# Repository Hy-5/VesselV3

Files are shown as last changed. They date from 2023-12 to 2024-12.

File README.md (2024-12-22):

# Vessel (rev 1.0)

Schematics

PCB 3D View

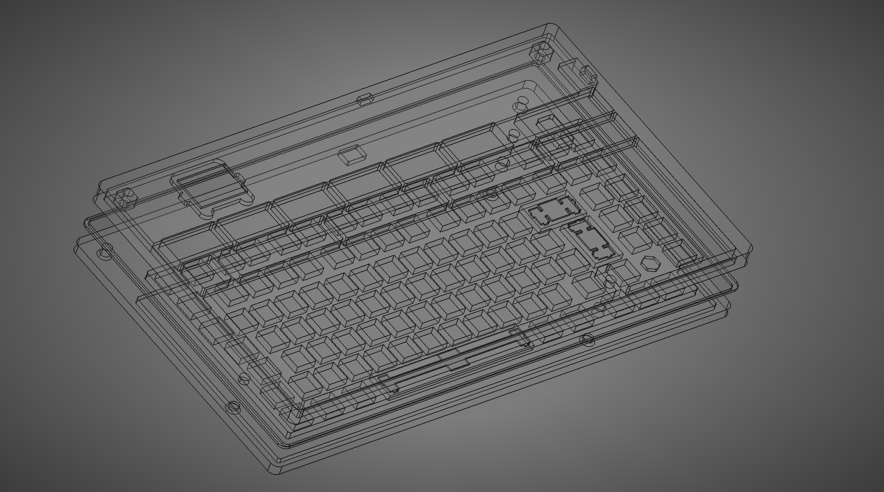
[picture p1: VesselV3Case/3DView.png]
Case 3D Model


Case Turntable

PCB before soldering

Soldered PCB

RgbOFF

Side View

RgbON

*ISO-FR 75-ish keyboard with I2C OLED, RGB (WS2812B-2020) and rotary encoder*

* Keyboard Maintainer: [Hy-5 (Ismael Coulibaly)](https://github.com/Hy-5)
* Hardware Supported: *STM32F446RET6TR*

[WIP]

Make example for this keyboard (after setting up your build environment):

    qmk compile -kb vessel -km base 2>&1 | ts '%Y-%m-%d %H:%M:%S

Flashing example for this keyboard:

    A - Initial flashing
        1 - Bridge "boot0 to 3v3_1" solder jumper to pull boot0 high
        2 - Desolder logic level shifter to keep boot1 pin low
        3 - Plug in the keyboard, it will boot in dfu bootloader mode
        4 - Use whatever program you prefer, QMK Toolbox, STM32 Programmer, STLink V2 etc.
    B - After initial flashing
        1 - Keep M12 button (row0, col11) pressed while plugging in the keyboard to launch in bootloader mode
        2 - Use QMK Toolbox for flashing

See the [build environment setup](https://docs.qmk.fm/#/getting_started_build_tools) and the [make instructions](https://docs.qmk.fm/#/getting_started_make_guide) for more information. Brand new to QMK? Start with our [Complete Newbs Guide](https://docs.qmk.fm/#/newbs).

## Bootloader

Enter the bootloader in 1 way:

* **Bootmagic reset**: Hold down the M12 key at ((row0, col11) in the matrix) and plug in the keyboard

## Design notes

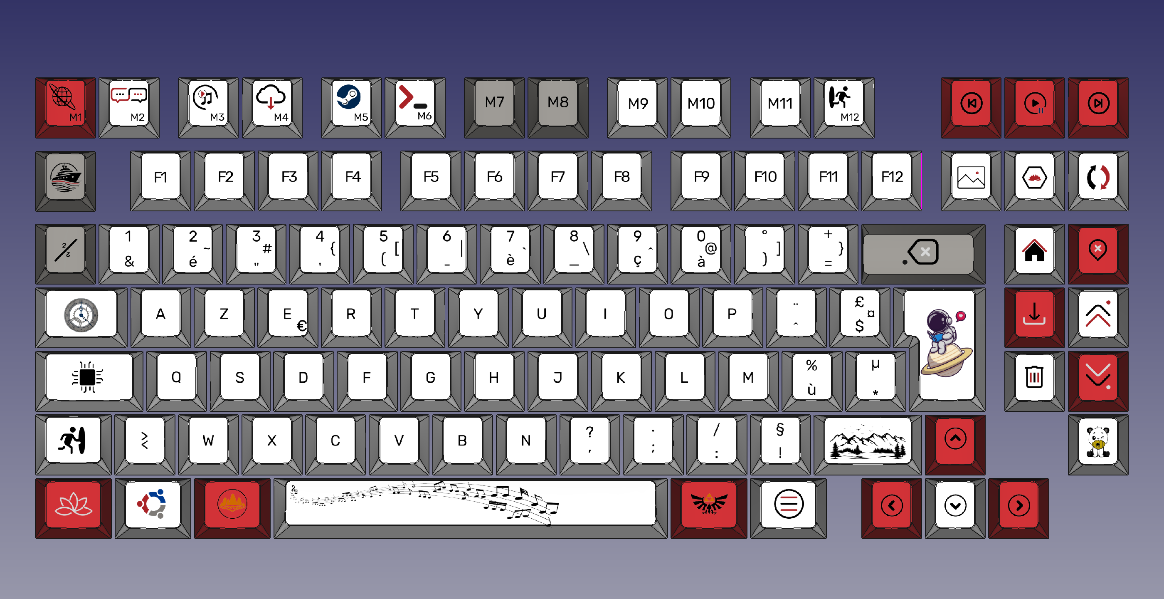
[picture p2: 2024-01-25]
VesselV3Case/Keycaps_Render.png

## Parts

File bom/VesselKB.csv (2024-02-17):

null | Sourced | Placed | References | Value | Footprint | DigikeyPartNumber | Manufacturer_Name | Manufacturer_Part_Number | Mouser Part Number | Quantity
1 |  |  | C3, C6, C7, C8, C16, C17, C19, C20, C21, C22, C23, C24 | 0.1u | C0805 | 399-C0805C104J8RAC7800TR-ND | KEMET | C0805C104J8RACTU | 80-C0805C104J8R | 12
2 |  |  | C9, C10, C11, C12, C13, C14, C15, C18, C29 | 4.7u | C0805 | 399-15708-2-ND | KEMET | C0805C475J8RACAUTO | 80-C0805C475J8RAUTO | 9
3 |  |  | C25, C26, C27 | 10n | CAPC2012X135N | 732-7579-2-ND | Wurth Elektronik | 885012007009 | 710-885012007009 | 3
4 |  |  | C1, C2 | 20pF | C0603 | 399-C0603C200G8HAC7867TR-ND | KEMET | C0603C200G8HACTU | 80-C0603C200G8HACTU | 2
5 |  |  | C4, C5 | 1u | CAPC2012X140N | 478-KGM21AR71A105JUTR-ND | AVX | 0805ZC105JAT2A | 581-0805ZC105JAT2A | 2
6 |  |  | C33 | c=10u | CAPC2012X135N | 1276-2402-2-ND | SAMSUNG | CL21A106KPFNNNF | 187-CL21A106KPFNNNF | 1
7 |  |  | R4, R12, R13, R14, R16, R18, R19, R21, R22 | 10k | RESC2012X50N | 541-CRCW080510K0JNECTR-ND | Vishay | CRCW080510K0JNEC | 71-CRCW080510K0JNEC | 9
8 |  |  | R1, R2 | r=5100 | RESC2012X60N | 2019-RK73H2ATTD5101FTR-ND | KOA Speer | RK73H2ATTD5101F | 660-RK73H2ATTD5101F | 2
9 |  |  | R10 | 320 | RESC1005X40N | 2019-RN73H1ETTP3200D25TR-ND | KOA Speer | RN73H1ETTP3200D25 | 660-RN73H1ETP3200D25 | 1
10 |  |  | R11 | r=22 | RESC2012X60N | CR0805-FX-22R0ELFTR-ND | Bourns | CR0805-FX-22R0ELF | 652-CR0805FX-22R0ELF | 1
11 |  |  | D1, D2, D3, D4, D5, D6, D7, D8, D9, D10, D11, D12, D13, D14, D15, D16, D17, D18, D19, D20, D21, D22, D23, D24, D25, D26, D27, D28, D29, D30, D31, D32, D33, D34, D35, D36, D37, D38, D39, D40, D41, D42, D43, D44, D45, D46, D47, D48, D49, D50, D51, D52, D53, D54, D55, D56, D57, D58, D59, D60, D61, D62, D63, D64, D65, D66, D67, D68, D69, D70, D71, D72, D73, D74, D75, D76, D77, D78, D79, D80, D81, D82, D83, D84, D85, D86, D87, D88, D89, D90, D91, D92, D93, D94, D95, D96, D97, D98, D99, D100, D101, D102 | D_Small | SODFL3816X120N | 4878-1N4148WTR-ND | Diotec Semiconductor | 1N4148W | 637-1N4148W | 102
12 |  |  | D103 | USBLC6-2SC6Y | SOT95P280X145-6N | 497-11882-2-ND | STMicroelectronics | USBLC6-2SC6Y | 511-USBLC6-2SC6Y | 1
13 |  |  | Y1 | 25MHz | ATS25ASM1E | CTX1144TR-ND | CTS | ATS25ASM-1E | 774-ATS25ASM-1E | 1
14 |  |  | (AND_Gate)IC6 | 74AUP1G09GW-Q100H | SOT65P212X110-5N | 1727-74AUP1G09GW-Q100HTR-ND | Nexperia | 74AUP1G09GW-Q100H | 771-74AUP1G09GWQ100H | 1
15 |  |  | (BidirectionalLogicLevelShifter)IC4 | TXB0104PWR | SOP65P640X120-14N | 296-21929-2-ND | Texas Instruments | TXB0104PWR | 595-TXB0104PWR | 1
16 |  |  | (LDORegulator)IC1 | AP2112K-3.3TRG1 | SOT95P282X130-5N | AP2112K-3.3TRG1DITR-ND | Diodes Incorporated | AP2112K-3.3TRG1 | 621-AP2112K-3.3TRG1 | 1
17 |  |  | (LF50ABDT-TR)-IC3 | 5VOutput_VoltageRegulator | TO228P972X240-3N | 497-8344-2-ND | STMicroelectronics | LF50ABDT-TR | 511-LF50ABDT-TR | 1
18 |  |  | MCU1 | STM32F446RET6TR | QFP50P1200X1200X160-64N | 497-STM32F446RET6TR-ND | STMicroelectronics | STM32F446RET6TR | 511-STM32F446RET6TR | 1
19 |  |  | Polyfuse1 | 500mA | 1206L05015YR | F3733TR-ND | LITTELFUSE | 1206L050/15YR | 576-1206L050/15YR | 1
20 |  |  | Q1 | BC856A,215 | SOT95P230X110-3N | 1727-4242-2-ND | Nexperia | BC856A,215 | 771-BC856A-T/R | 1
21 |  |  | Rotary_Encoder(20mm)_S4 | PEC12R-3220F-S0024 | PEC12R3220FS0024 | PEC12R-3220F-S0024-ND | Bourns | PEC12R-3220F-S0024 | 652-PEC12R3220FS0024 | 1
22 |  |  | S6 | On/On SPDT | SW_L102021ML04Q | CKC5102-ND | C&K | L102021ML04Q | 611-L102021ML04Q | 1
23 |  |  | Schottky/ReversPolProtec1 | PMEG2010ER,115 | PMEG2010ER115 | 1727-5192-2-ND | Nexperia | PMEG2010ER,115 | 771-PMEG2010ER115 | 1
24 |  |  | TVSDiode/ESDSuppr1 | SMF6.0CA | SODFL3618X108N | 18-SMF6.0CATR-ND | LITTELFUSE | SMF6.0CA | 576-SMF6.0CA | 1
25 |  |  | USB-C1 | USB4800-03-A | USB480003A | 2073-USB4800-03-ATR-ND | GCT (GLOBAL CONNECTOR TECHNOLOGY) | USB4800-03-A | 640-USB4800-03-A | 1
26 |  |  | J1 | JTAG/SWD 10pins Headers | HUSSP10W40P127_2X5_635X340X420P | 952-4189-2-ND | Harwin | M50-3600542R | 855-M50-3600542R | 1

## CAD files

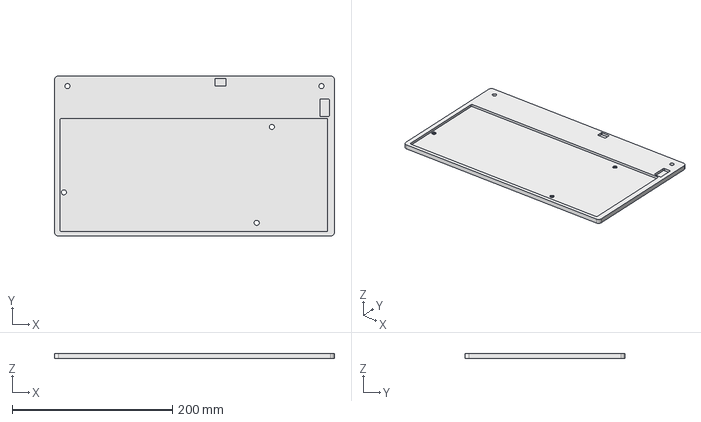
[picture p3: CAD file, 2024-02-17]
VesselV3Case/Final Models/1 - BottomLayer.step
350.0 x 200.0 x 6.50 mm

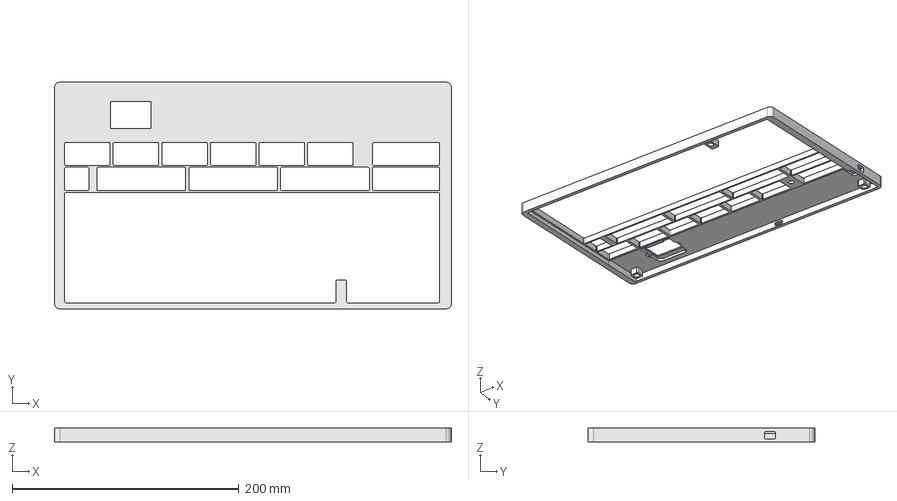
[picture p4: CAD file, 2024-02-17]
VesselV3Case/Final Models/2 - TopLayer.step
350.0 x 200.0 x 12.0 mm

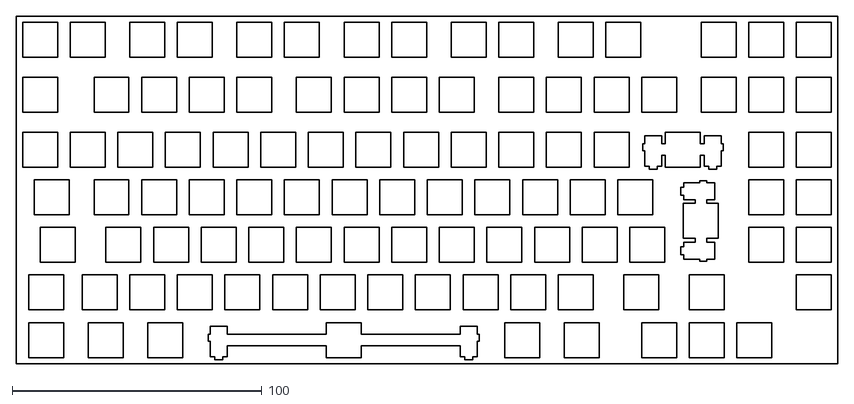
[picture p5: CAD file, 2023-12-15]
VesselV3Case/SwitchLayer/UpdatedSwitchLayer.dxf
328.6 x 139.1

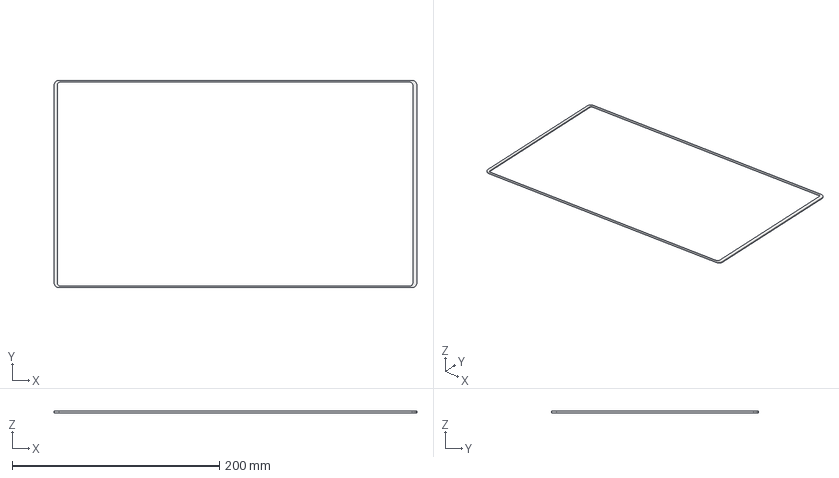
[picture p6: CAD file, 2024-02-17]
VesselV3Case/Final Models/4 - SideLayer.step
350.0 x 200.0 x 1.60 mm

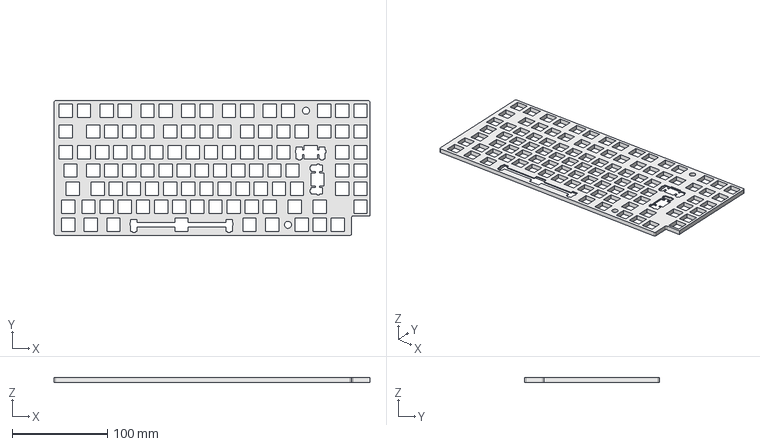
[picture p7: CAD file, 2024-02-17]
VesselV3Case/Final Models/3 - SwitchLayer.step
332.0 x 141.5 x 5.00 mm

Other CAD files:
VesselV3Case/SwitchLayer/SwitchLayerFile.FCStd
Silkscreen DXF/OLD_VesselV3-F_Silkscreen.dxf
Silkscreen DXF/VesselV3-F_Silkscreen.dxf

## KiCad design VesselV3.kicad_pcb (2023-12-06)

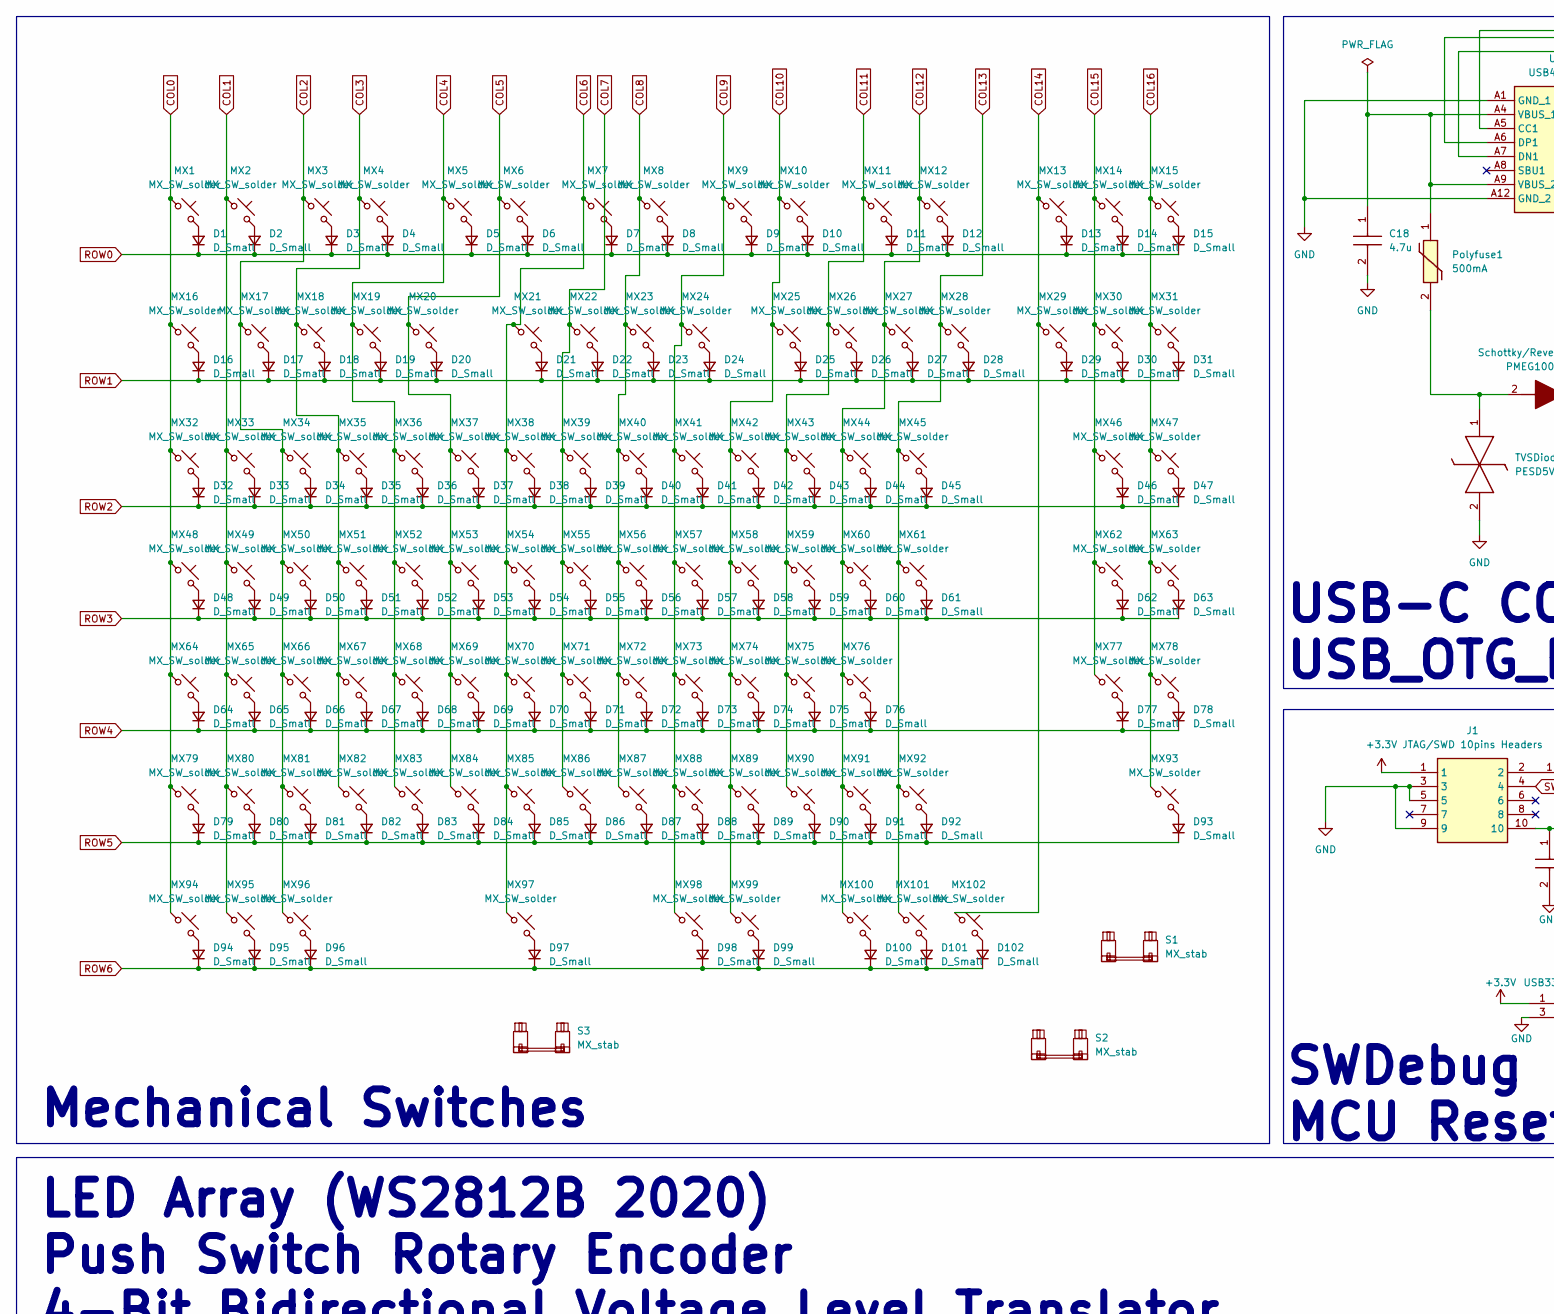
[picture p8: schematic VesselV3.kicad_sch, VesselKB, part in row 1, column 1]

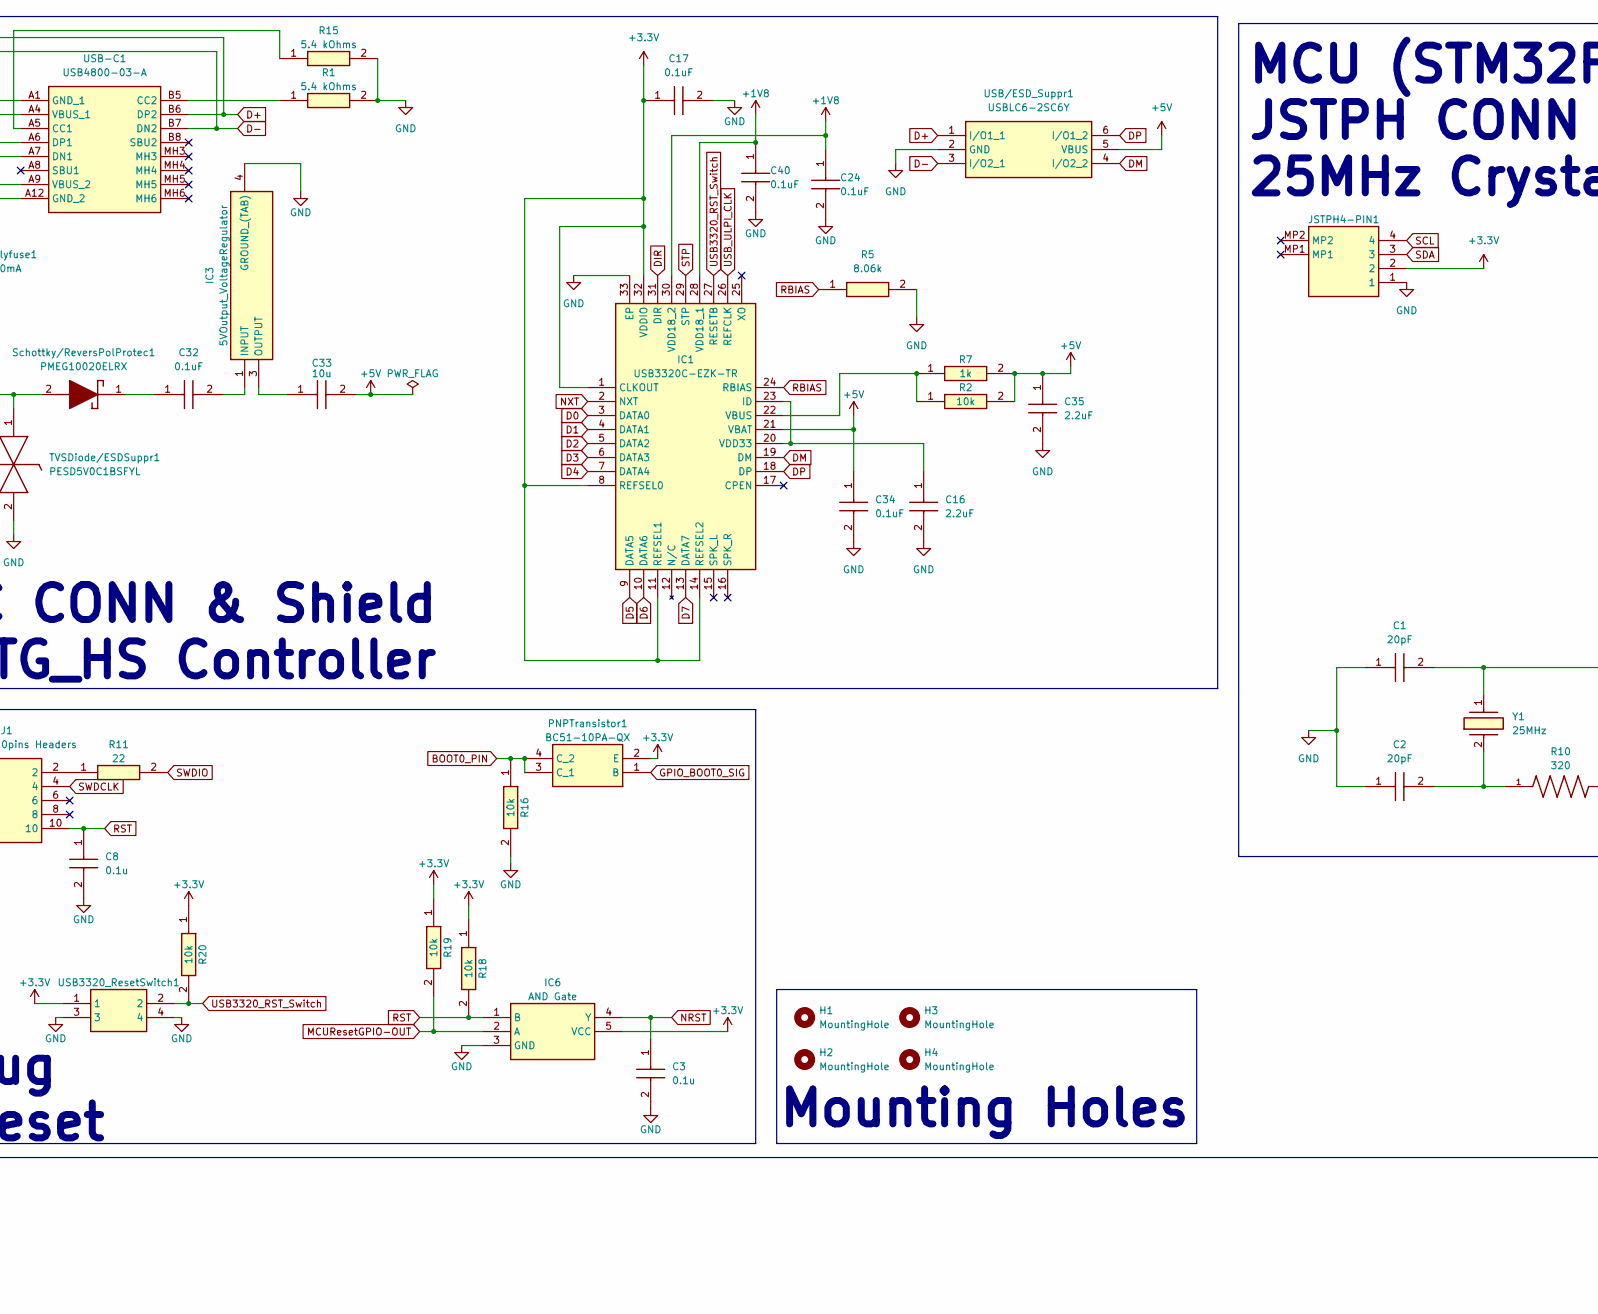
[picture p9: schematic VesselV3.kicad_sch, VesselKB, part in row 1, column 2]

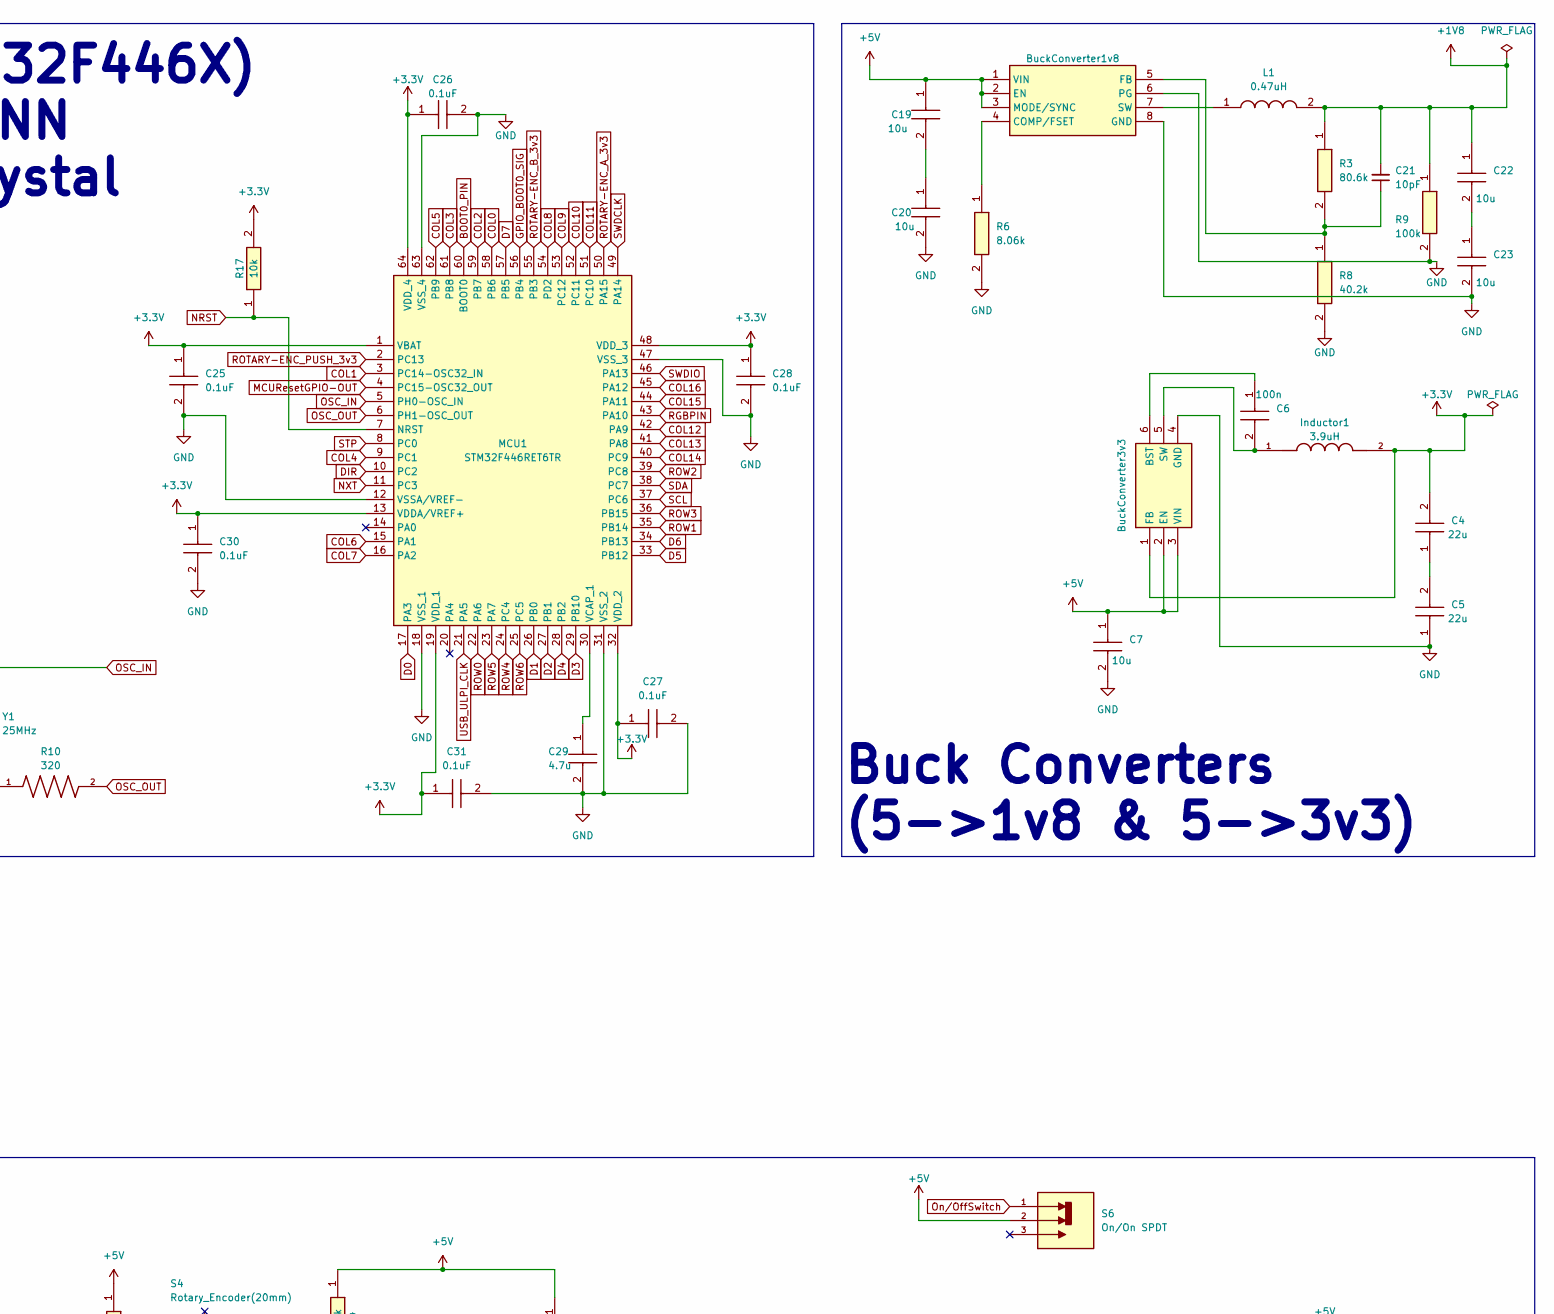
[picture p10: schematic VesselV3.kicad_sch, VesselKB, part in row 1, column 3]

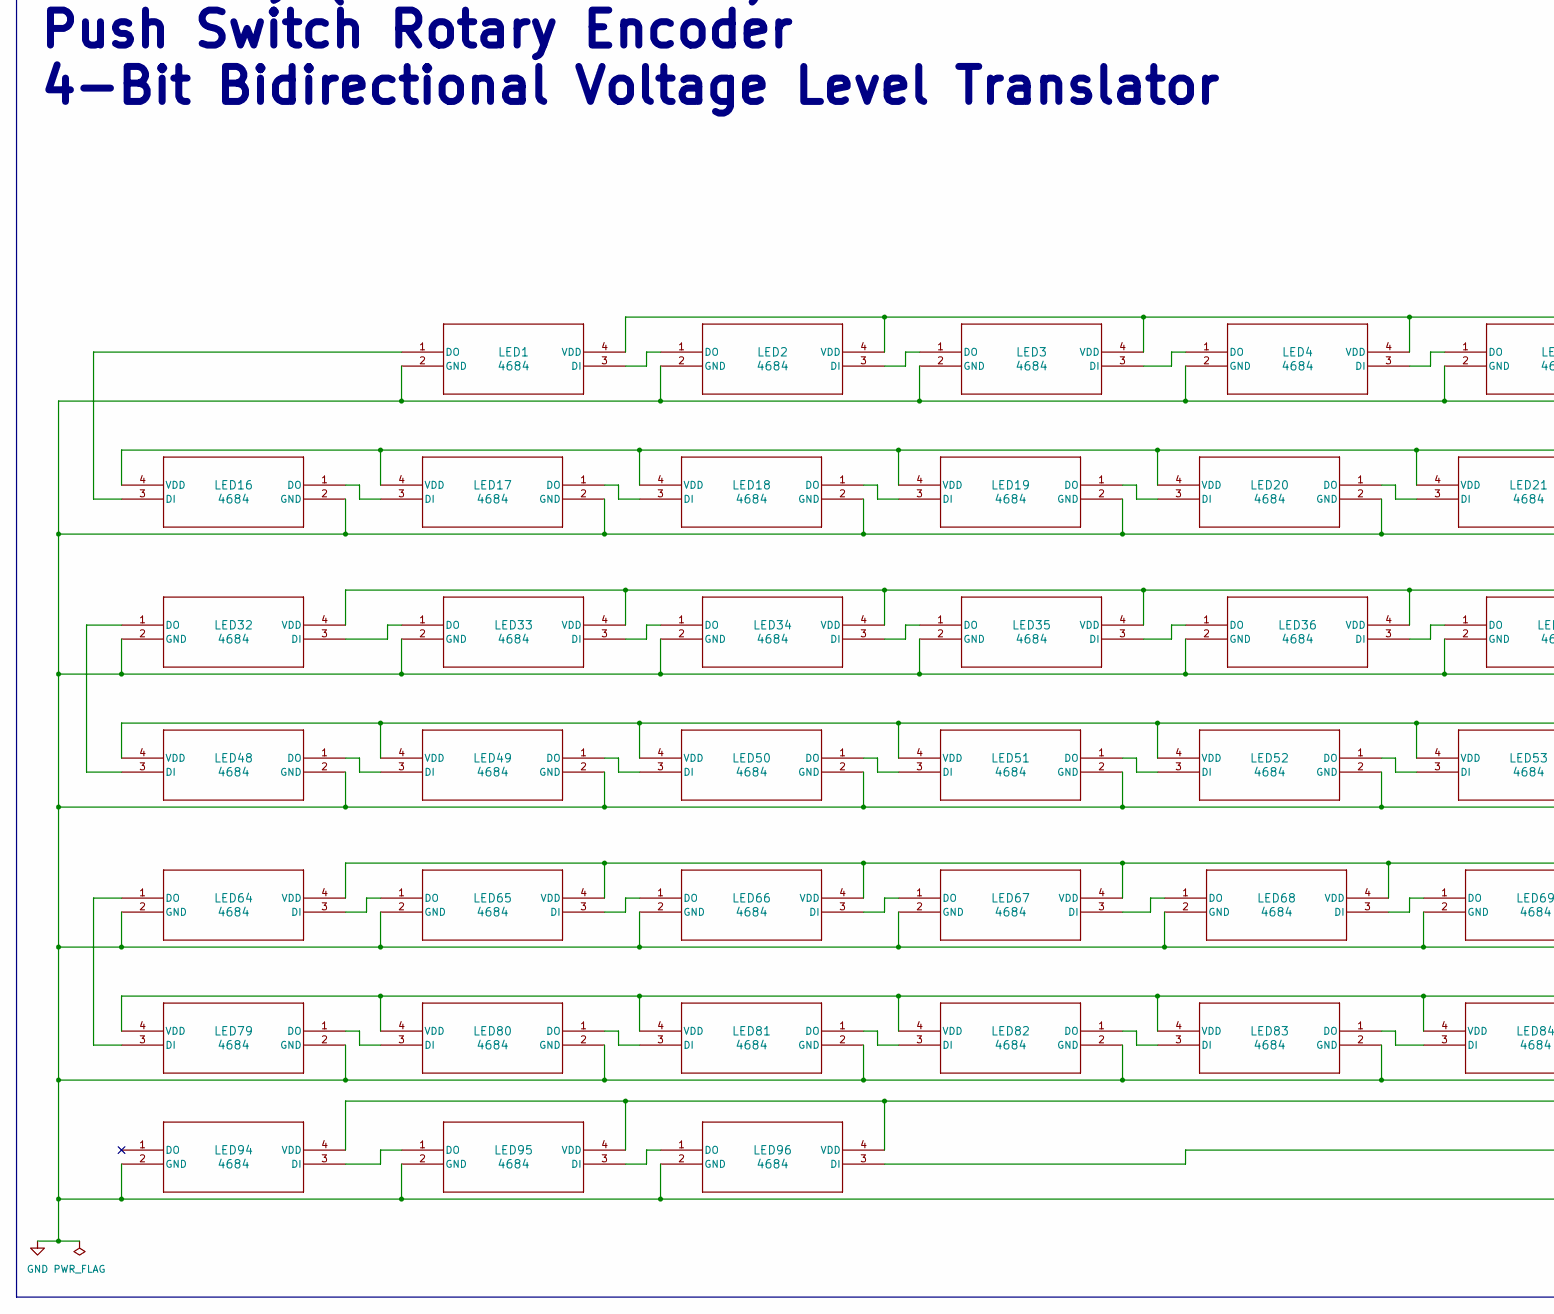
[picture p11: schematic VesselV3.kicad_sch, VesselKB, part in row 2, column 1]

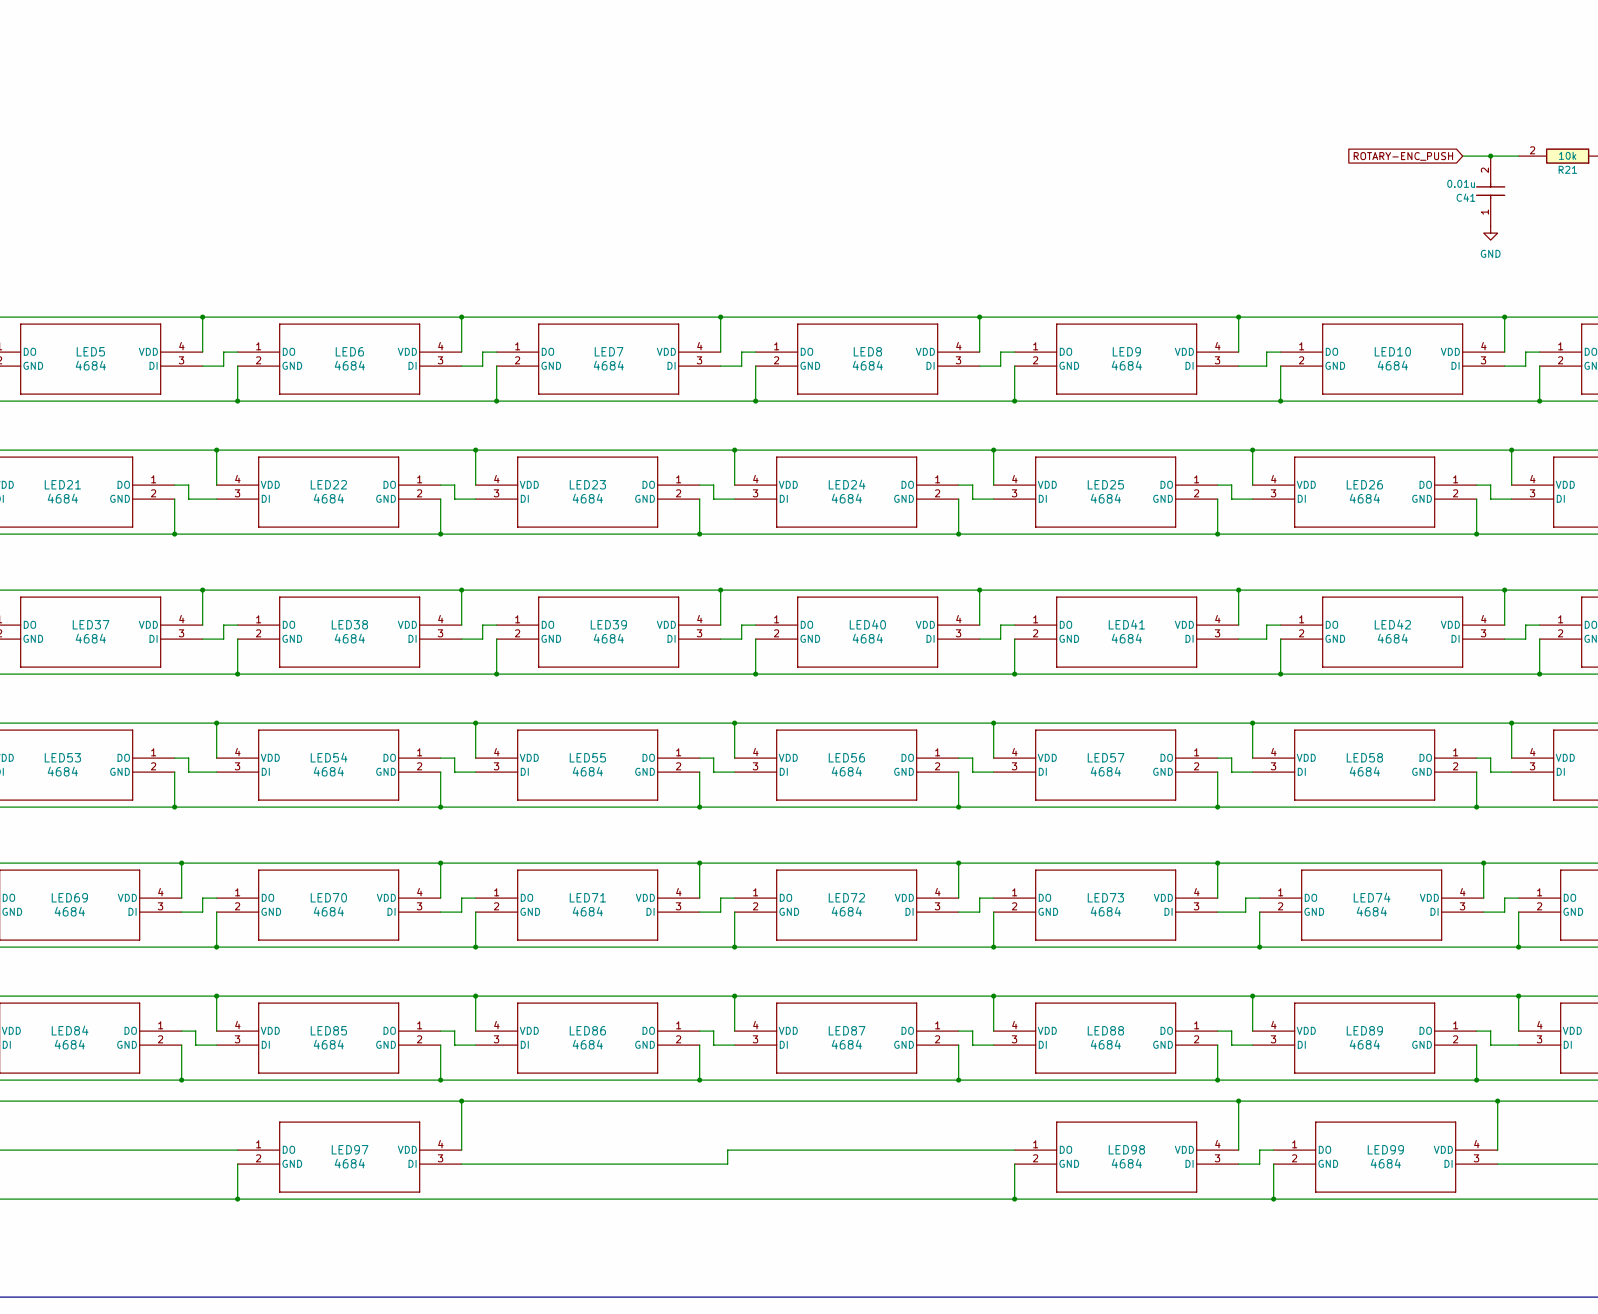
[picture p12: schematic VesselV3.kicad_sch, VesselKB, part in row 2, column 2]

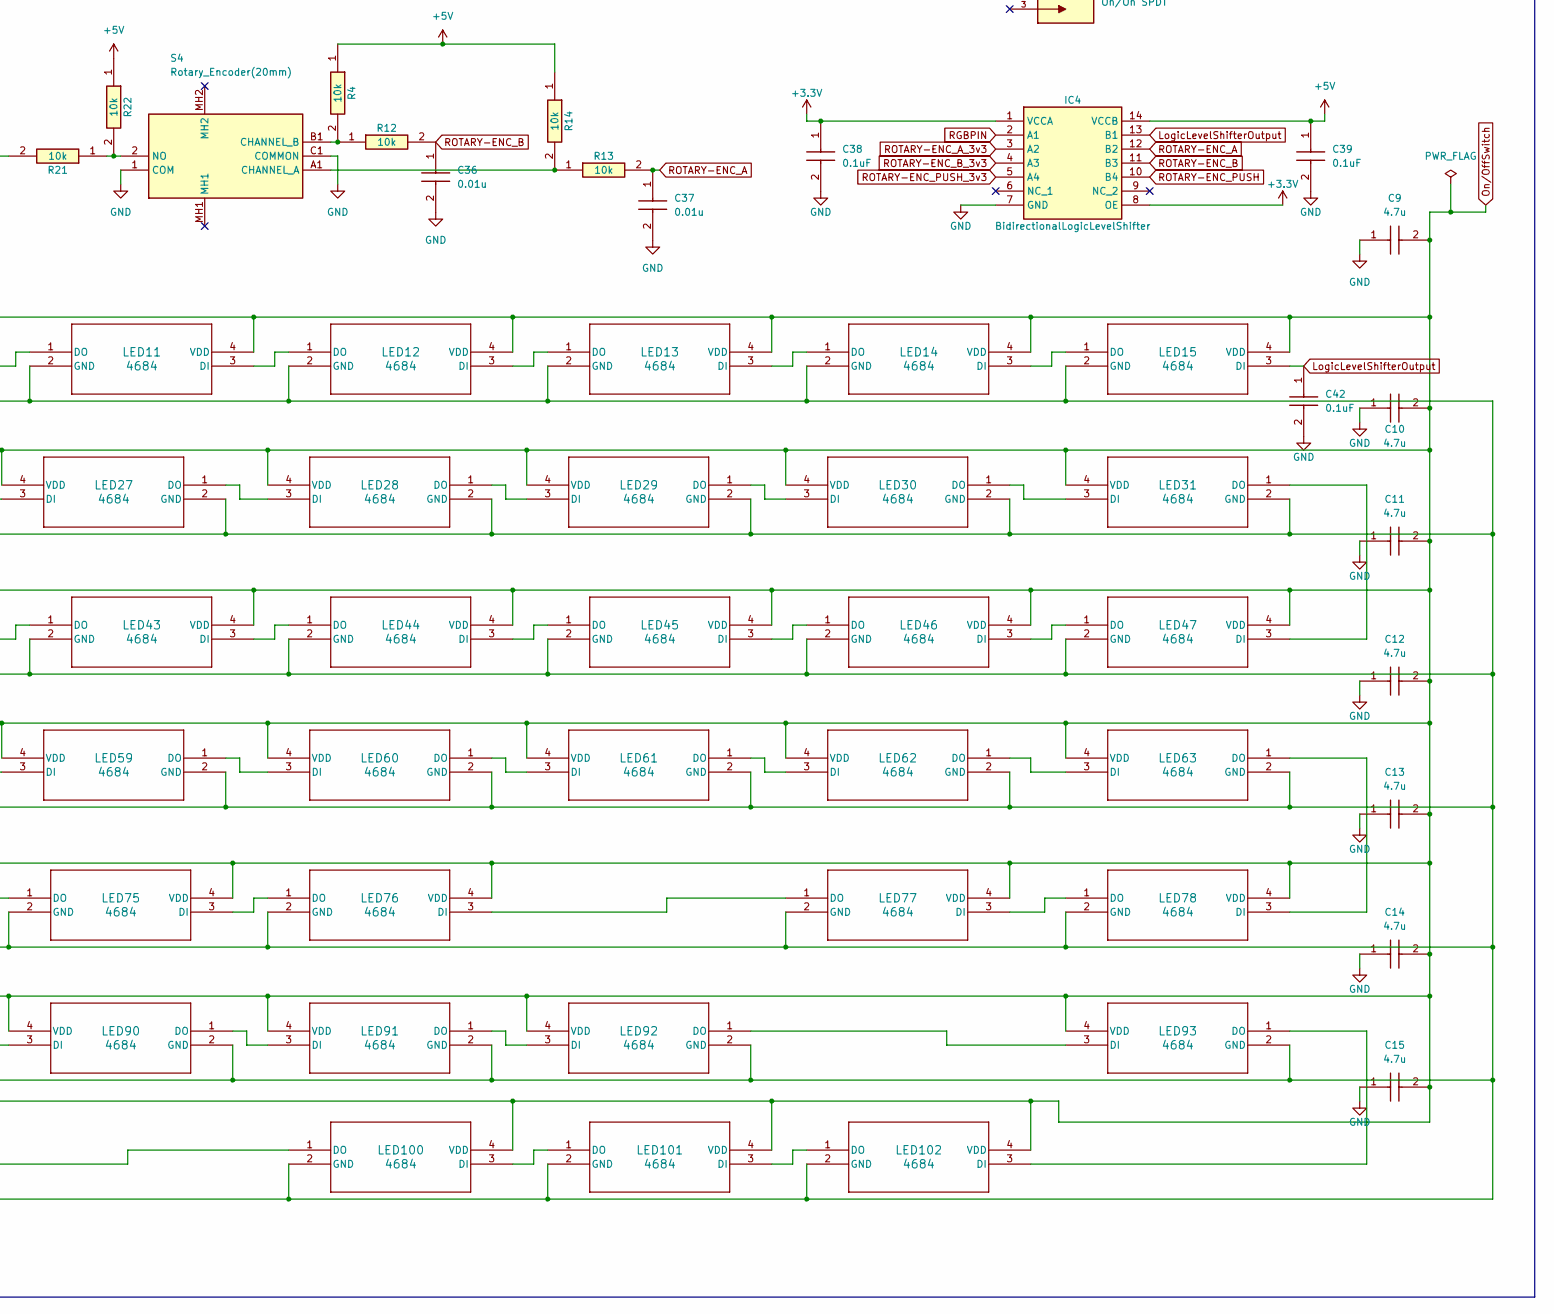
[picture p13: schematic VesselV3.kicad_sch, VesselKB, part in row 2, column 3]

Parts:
BuckConverter1v8: TPS6285010MQDRLRQ1; SOTFL50P160X60-8N; Mouser Part Number 595-S6285010MQDRLRQ1
BuckConverter3v3: AP63203WU-7; SOT95P280X100-6N; Mouser Part Number 621-AP63203WU-7
C1, C2: 20pF; C0603; Mouser Part Number 80-C0603C200G8HACTU
C3, C8: 0.1u; C0805; Mouser Part Number 80-C0805C104J8R
C4, C5: c=2.2e-05; CAPC2012X95N; Mouser Part Number 187-CL21A226KQCLRNC
C6: c=1e-07; CAPC2012X95N; Mouser Part Number 187-CL21B104KBCNNNC
C7, C19, C20, C22, C23, C33: c=1e-05; CAPC2012X140N; Mouser Part Number 187-CL21A106KOQNNNE
C9, C10, C11, C12, C13, C14, C15, C18, C29: 4.7u; C0805; Mouser Part Number 80-C0805C475J8RAUTO
C16, C35: 2.2uF; CAPC1608X90N; Mouser Part Number 187-CL10B225KP8NNNC
C17, C24, C25, C26, C27, C28, C30, C31, C32, C34, C38, C39, C40, C42: 0.1uF; CAPC1005X55N; Mouser Part Number 81-GRM155R71A104JA1D
C21: 10pF; CAPC2012X75N; Manufacturer_Part_Number CL21C100CBANNNC; DigikeyPartNumber 1276-2561-2-ND
C36, C37, C41: 0.01u; CAPC1005X56N; Mouser Part Number 581-0402ZC103JAT2A
D1, D2, D3, D4, D5, D6, D7, D8, D9, D10, D11, D12, D13, D14, D15, D16, D17, D18, D19, D20, D21, D22, D23, D24, D25, D26, D27, D28, D29, D30, D31, D32, D33, D34, D35, D36, D37, D38, D39, D40, D41, D42, D43, D44, D45, D46, D47, D48, D49, D50, D51, D52, D53, D54, D55, D56, D57, D58, D59, D60, D61, D62, D63, D64, D65, D66, D67, D68, D69, D70, D71, D72, D73, D74, D75, D76, D77, D78, D79, D80, D81, D82, D83, D84, D85, D86, D87, D88, D89, D90, D91, D92, D93, D94, D95, D96, D97, D98, D99, D100, D101, D102: D_Small; SODFL3816X120N; Manufacturer_Part_Number 1N4148W; DigikeyPartNumber 4878-1N4148WTR-ND
H1, H2, H3, H4: MountingHole; MountingHole_2.5mm_Pad_TopBottom
IC1: USB3320C-EZK-TR; QFN50P500X500X100-33N-D; Mouser Part Number 886-USB3320C-EZK-TR
IC3: 5VOutput_VoltageRegulator; TO228P972X240-3N; Mouser Part Number 511-LF50ABDT-TR
IC4: BidirectionalLogicLevelShifter; SOP65P640X120-14N; Mouser Part Number 595-TXB0104PWR
IC6: AND Gate; SOT65P212X110-5N; Mouser Part Number 771-74AUP1G09GWQ100H
Inductor1: 3.9uH; IND_LQH32NH3R9J23L; PARTREV N/A; Mouser Part Number 81-LQH32NH3R9J23L
J1: JTAG/SWD 10pins Headers; HUSSP10W40P127_2X5_635X340X420P; Mouser Part Number 855-M50-3600542R
JSTPH4-PIN1: 4392; Mouser Part Number 485-4392
L1: 0.47uH; INDC2012X105N; Mouser Part Number 810-MLZ2012DR47DT000
LED1, LED2, LED3, LED4, LED5, LED6, LED7, LED8, LED9, LED10, LED11, LED12, LED13, LED14, LED15, LED16, LED17, LED18, LED19, LED20, LED21, LED22, LED23, LED24, LED25, LED26, LED27, LED28, LED29, LED30, LED31, LED32, LED33, LED34, LED35, LED36, LED37, LED38, LED39, LED40, LED41, LED42, LED43, LED44, LED45, LED46, LED47, LED48, LED49, LED50, LED51, LED52, LED53, LED54, LED55, LED56, LED57, LED58, LED59, LED60, LED61, LED62, LED63, LED64, LED65, LED66, LED67, LED68, LED69, LED70, LED71, LED72, LED73, LED74, LED75, LED76, LED77, LED78, LED79, LED80, LED81, LED82, LED83, LED84, LED85, LED86, LED87, LED88, LED89, LED90, LED91, LED92, LED93, LED94, LED95, LED96, LED97, LED98, LED99, LED100, LED101, LED102: 4684; 4684_ADA; Manufacturer_Part_Number 4684; DigikeyPartNumber 1528-4684-ND
MCU1: STM32F446RET6TR; QFP50P1200X1200X160-64N; Mouser Part Number 511-STM32F446RET6TR
MX1, MX2, MX3, MX4, MX5, MX6, MX7, MX8, MX9, MX10, MX11, MX12, MX13, MX14, MX15, MX16, MX17, MX18, MX19, MX20, MX21, MX22, MX23, MX24, MX25, MX26, MX27, MX28, MX29, MX30, MX31, MX32, MX33, MX34, MX35, MX36, MX37, MX38, MX39, MX40, MX41, MX42, MX43, MX44, MX46, MX47, MX49, MX50, MX51, MX52, MX53, MX54, MX55, MX56, MX57, MX58, MX59, MX60, MX62, MX63, MX65, MX66, MX67, MX68, MX69, MX70, MX71, MX72, MX73, MX74, MX75, MX76, MX77, MX78, MX80, MX81, MX82, MX83, MX84, MX85, MX86, MX87, MX88, MX89, MX90, MX92, MX93, MX100, MX101, MX102: MX_SW_solder; SW_Cherry_MX_PCB_1.00u
MX45: MX_SW_solder; SW_Cherry_MX_PCB_2.00u
MX48: MX_SW_solder; SW_Cherry_MX_PCB_1.50u
MX61: MX_SW_solder; SW_Cherry_MX_PCB_ISOEnter
MX64, MX91: MX_SW_solder; SW_Cherry_MX_PCB_1.75u
MX79, MX94, MX95, MX96, MX98, MX99: MX_SW_solder; SW_Cherry_MX_PCB_1.25u
MX97: MX_SW_solder; SW_Cherry_MX_PCB_6.25u
PNPTransistor1: BC51-10PA-QX; BC55PASQX; Mouser Part Number 771-BC51-10PA-QX
Polyfuse1: 500mA; 1206L05015YR; Mouser Part Number 576-1206L050/15YR
R1, R15: 5.4 kOhms; RESC1005X40N; Mouser Part Number 755-ESR01MZPF5101
R2, R4, R12, R13, R14, R16, R17, R18, R19, R20, R21, R22: 10k; RESC2012X50N; Mouser Part Number 71-CRCW080510K0JNEC
R3: 80.6k; RESC2012X60N; Mouser Part Number 652-CR0805FX-8062ELF
R5, R6: 8.06k; RESC2012X60N; Mouser Part Number 660-RK73H2ATTD8061F
R7: 1k; RESC5025X65N; Mouser Part Number 652-CRS2010FX1001ELF
R8: 40.2k; ERJ6ENF1000V; Mouser Part Number 667-ERJ-6ENF4022V
R9: 100k; RESC2012X60N; Mouser Part Number 603-RC0805FR-07100KL
R10: 320; RESC1005X40N; Manufacturer_Part_Number RN73H1ETTP3200D25; DigikeyPartNumber 2019-RN73H1ETTP3200D25TR-ND
R11: 22; RESC2012X50N; Mouser Part Number 71-CRCW0805-22-E3
S1, S2: MX_stab; Stabilizer_Cherry_MX_2.00u
S3: MX_stab; Stabilizer_Cherry_MX_6.25u
S4: Rotary_Encoder(20mm); PEC12R3220FS0024; Mouser Part Number 652-PEC12R3220FS0024
S6: On/On SPDT; SW_L102021ML04Q; PARTREV N/A; DigikeyPartNumber CKC5102-ND
Schottky/ReversPolProtec1: PMEG10020ELRX; SODFL3517X110N; Mouser Part Number 771-PMEG10020ELRX
TVSDiode/ESDSuppr1: PESD5V0C1BSFYL; PMEG3005AESFYL; Mouser Part Number 771-PESD5V0C1BSFYL
USB3320_ResetSwitch1: SKQGABE010; SKQGAKE010; Mouser Part Number 688-SKQGAB
USB-C1: USB4800-03-A; USB480003A; Mouser Part Number 640-USB4800-03-A
USB/ESD_Suppr1: USBLC6-2SC6Y; SOT95P280X145-6N; Mouser Part Number 511-USBLC6-2SC6Y
Y1: 25MHz; ATS25ASM1E; Mouser Part Number 774-ATS25ASM-1E

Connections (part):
+1V8: C21.2, C22.1, C24.1, C40.1, IC1.28 (VDD18_1), IC1.30 (VDD18_2), L1.2, R3.1, R9.1
+3.3V: BuckConverter3v3.1 (FB), C4.2, C17.1, C25.1, C26.1, C27.1, C28.1, C30.1, C31.1, C38.1, IC1.1 (CLKOUT), IC1.8 (REFSEL0), IC1.11 (REFSEL1), IC1.14 (REFSEL2), IC1.32 (VDDIO), IC4.1 (VCCA), IC4.8 (OE), IC6.5 (VCC), Inductor1.2, J1.1, JSTPH4-PIN1.2, MCU1.1 (VBAT), MCU1.13 (VDDA/VREF+), MCU1.19 (VDD_1), MCU1.32 (VDD_2), MCU1.48 (VDD_3), MCU1.64 (VDD_4), PNPTransistor1.2 (E), R17.2, R18.1, R19.1, R20.1, USB3320_ResetSwitch1.1
+5V: BuckConverter1v8.1 (VIN), BuckConverter1v8.2 (EN), BuckConverter1v8.3 (MODE/SYNC), BuckConverter3v3.2 (EN), BuckConverter3v3.3 (VIN), C7.1, C19.1, C33.2, C34.1, C35.1, C39.1, IC1.21 (VBAT), IC4.14 (VCCB), R2.2, R4.1, R7.2, R14.1, R22.1, S6.2, USB/ESD_Suppr1.5 (VBUS)
BOOT0_PIN: MCU1.60 (BOOT0), PNPTransistor1.3 (C_1), PNPTransistor1.4 (C_2), R16.1
COL0: MCU1.58 (PB6), MX1.1, MX16.1, MX32.1, MX48.1, MX64.1, MX79.1, MX94.1
COL1: MCU1.3 (PC14-OSC32_IN), MX2.1, MX33.1, MX49.1, MX65.1, MX80.1, MX95.1
COL2: MCU1.59 (PB7), MX3.1, MX17.1, MX34.1, MX50.1, MX66.1, MX81.1, MX96.1
COL3: MCU1.61 (PB8), MX4.1, MX18.1, MX35.1, MX51.1, MX67.1, MX82.1
COL4: MCU1.9 (PC1), MX5.1, MX19.1, MX36.1, MX52.1, MX68.1, MX83.1
COL5: MCU1.62 (PB9), MX6.1, MX20.1, MX37.1, MX53.1, MX69.1, MX84.1
COL6: MCU1.15 (PA1), MX7.1, MX21.1, MX38.1, MX54.1, MX70.1, MX85.1, MX97.1
COL7: MCU1.16 (PA2), MX22.1, MX39.1, MX55.1, MX71.1, MX86.1
COL8: MCU1.54 (PD2), MX8.1, MX23.1, MX40.1, MX56.1, MX72.1, MX87.1
COL9: MCU1.53 (PC12), MX9.1, MX24.1, MX41.1, MX57.1, MX73.1, MX88.1, MX98.1
COL10: MCU1.52 (PC11), MX10.1, MX25.1, MX42.1, MX58.1, MX74.1, MX89.1, MX99.1
COL11: MCU1.51 (PC10), MX11.1, MX26.1, MX43.1, MX59.1, MX75.1, MX90.1
COL12: MCU1.42 (PA9), MX12.1, MX27.1, MX44.1, MX60.1, MX76.1, MX91.1, MX100.1
COL13: MCU1.41 (PA8), MX28.1, MX45.1, MX61.1, MX92.1, MX101.1
COL14: MCU1.40 (PC9), MX13.1, MX29.1, MX102.1
COL15: MCU1.44 (PA11), MX14.1, MX30.1, MX46.1, MX62.1, MX77.1
COL16: MCU1.45 (PA12), MX15.1, MX31.1, MX47.1, MX63.1, MX78.1, MX93.1
D0: IC1.3 (DATA0), MCU1.17 (PA3)
D1: IC1.4 (DATA1), MCU1.26 (PB0)
D2: IC1.5 (DATA2), MCU1.27 (PB1)
D3: IC1.6 (DATA3), MCU1.29 (PB10)
D4: IC1.7 (DATA4), MCU1.28 (PB2)
D5: IC1.9 (DATA5), MCU1.33 (PB12)
D6: IC1.10 (DATA6), MCU1.34 (PB13)
D7: IC1.13 (DATA7), MCU1.57 (PB5)
D+: USB-C1.A6 (DP1), USB-C1.B6 (DP2), USB/ESD_Suppr1.1 (I/O1_1)
D-: USB-C1.A7 (DN1), USB-C1.B7 (DN2), USB/ESD_Suppr1.3 (I/O2_1)
DIR: IC1.31 (DIR), MCU1.10 (PC2)
DM: IC1.19 (DM), USB/ESD_Suppr1.4 (I/O2_2)
DP: IC1.18 (DP), USB/ESD_Suppr1.6 (I/O1_2)
GND: BuckConverter1v8.6 (PG), BuckConverter1v8.8 (GND), BuckConverter3v3.4 (GND), C1.1, C2.1, C3.2, C5.1, C7.2, C8.2, C9.1, C10.1, C11.1, C12.1, C13.1, C14.1, C15.1, C16.2, C17.2, C18.2, C20.2, C23.2, C24.2, C25.2, C26.2, C27.2, C28.2, C29.2, C30.2, C31.2, C34.2, C35.2, C36.2, C37.2, C38.2, C39.2, C40.2, C41.1, C42.2, IC1.33 (EP), IC3.4 (GROUND_(TAB)), IC4.7 (GND), IC6.3 (GND), J1.3, J1.5, J1.9, JSTPH4-PIN1.1, LED1.2 (GND), LED2.2 (GND), LED3.2 (GND), LED4.2 (GND), LED5.2 (GND), LED6.2 (GND), LED7.2 (GND), LED8.2 (GND), LED9.2 (GND), LED10.2 (GND), LED11.2 (GND), LED12.2 (GND), LED13.2 (GND), LED14.2 (GND), LED15.2 (GND), LED16.2 (GND), LED17.2 (GND), LED18.2 (GND), LED19.2 (GND), LED20.2 (GND), LED21.2 (GND), LED22.2 (GND), LED23.2 (GND), LED24.2 (GND), LED25.2 (GND), LED26.2 (GND), LED27.2 (GND), LED28.2 (GND), LED29.2 (GND), LED30.2 (GND), LED31.2 (GND), LED32.2 (GND), LED33.2 (GND), LED34.2 (GND), LED35.2 (GND), LED36.2 (GND)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
GPIO_BOOT0_SIG: MCU1.56 (PB4), PNPTransistor1.1 (B)
LogicLevelShifterOutput: C42.1, IC4.13 (B1), LED15.3 (DI)
MCUResetGPIO-OUT: IC6.2 (A), MCU1.4 (PC15-OSC32_OUT), R19.2
NRST: C3.1, IC6.4 (Y), MCU1.7 (NRST), R17.1
NXT: IC1.2 (NXT), MCU1.11 (PC3)
unnamed: BuckConverter1v8.4 (COMP/FSET), R6.1
unnamed: BuckConverter1v8.5 (FB), C21.1, R3.2, R8.1
unnamed: BuckConverter1v8.7 (SW), L1.1
unnamed: BuckConverter3v3.6 (BST), C6.1
unnamed: BuckConverter3v3.5 (SW), C6.2, Inductor1.1
unnamed: C4.1, C5.2
unnamed: C19.2, C20.1
unnamed: C22.2, C23.1
unnamed: D1.2 (A), MX1.2
unnamed: D2.2 (A), MX2.2
unnamed: D3.2 (A), MX3.2
unnamed: D4.2 (A), MX4.2
unnamed: D5.2 (A), MX5.2
unnamed: D6.2 (A), MX6.2
unnamed: D7.2 (A), MX7.2
unnamed: D8.2 (A), MX8.2
unnamed: D9.2 (A), MX9.2
unnamed: D10.2 (A), MX10.2
unnamed: D11.2 (A), MX11.2
unnamed: D12.2 (A), MX12.2
unnamed: D13.2 (A), MX13.2
unnamed: D14.2 (A), MX14.2
unnamed: D15.2 (A), MX15.2
unnamed: D16.2 (A), MX16.2
unnamed: D17.2 (A), MX17.2
unnamed: D18.2 (A), MX18.2
unnamed: D19.2 (A), MX19.2
unnamed: D20.2 (A), MX20.2
unnamed: D21.2 (A), MX21.2
unnamed: D22.2 (A), MX22.2
unnamed: D23.2 (A), MX23.2
unnamed: D24.2 (A), MX24.2
unnamed: D25.2 (A), MX25.2
unnamed: D26.2 (A), MX26.2
unnamed: D27.2 (A), MX27.2
unnamed: D28.2 (A), MX28.2
unnamed: D29.2 (A), MX29.2
unnamed: D30.2 (A), MX30.2
unnamed: D31.2 (A), MX31.2
unnamed: D32.2 (A), MX32.2
unnamed: D33.2 (A), MX33.2
unnamed: D34.2 (A), MX34.2
unnamed: D35.2 (A), MX35.2
unnamed: D36.2 (A), MX36.2
unnamed: D37.2 (A), MX37.2
unnamed: D38.2 (A), MX38.2
unnamed: D39.2 (A), MX39.2
unnamed: D40.2 (A), MX40.2
unnamed: D41.2 (A), MX41.2
unnamed: D42.2 (A), MX42.2
unnamed: D43.2 (A), MX43.2
unnamed: D44.2 (A), MX44.2
unnamed: D45.2 (A), MX45.2
unnamed: D46.2 (A), MX46.2
unnamed: D47.2 (A), MX47.2
unnamed: D48.2 (A), MX48.2
unnamed: D49.2 (A), MX49.2
unnamed: D50.2 (A), MX50.2
unnamed: D51.2 (A), MX51.2
unnamed: D52.2 (A), MX52.2
unnamed: D53.2 (A), MX53.2
unnamed: D54.2 (A), MX54.2
unnamed: D55.2 (A), MX55.2
unnamed: D56.2 (A), MX56.2
unnamed: D57.2 (A), MX57.2
unnamed: D58.2 (A), MX58.2
unnamed: D59.2 (A), MX59.2
unnamed: D60.2 (A), MX60.2
unnamed: D61.2 (A), MX61.2
unnamed: D62.2 (A), MX62.2
unnamed: D63.2 (A), MX63.2
unnamed: D64.2 (A), MX64.2
unnamed: D65.2 (A), MX65.2
unnamed: D66.2 (A), MX66.2
unnamed: D67.2 (A), MX67.2
unnamed: D68.2 (A), MX68.2
unnamed: D69.2 (A), MX69.2
unnamed: D70.2 (A), MX70.2
unnamed: D71.2 (A), MX71.2
unnamed: D72.2 (A), MX72.2
unnamed: D73.2 (A), MX73.2
unnamed: D74.2 (A), MX74.2
unnamed: D75.2 (A), MX75.2
unnamed: D76.2 (A), MX76.2
unnamed: D77.2 (A), MX77.2
unnamed: D78.2 (A), MX78.2
unnamed: D79.2 (A), MX79.2
unnamed: D80.2 (A), MX80.2
unnamed: D81.2 (A), MX81.2
unnamed: D82.2 (A), MX82.2
unnamed: D83.2 (A), MX83.2
unnamed: D84.2 (A), MX84.2
unnamed: D85.2 (A), MX85.2
unnamed: D86.2 (A), MX86.2
unnamed: D87.2 (A), MX87.2
unnamed: D88.2 (A), MX88.2
unnamed: D89.2 (A), MX89.2
unnamed: D90.2 (A), MX90.2
unnamed: D91.2 (A), MX91.2
unnamed: D92.2 (A), MX92.2
unnamed: D93.2 (A), MX93.2
unnamed: D94.2 (A), MX94.2
unnamed: D95.2 (A), MX95.2
unnamed: D96.2 (A), MX96.2
unnamed: D97.2 (A), MX97.2
unnamed: D98.2 (A), MX98.2
unnamed: D99.2 (A), MX99.2
unnamed: D100.2 (A), MX100.2
unnamed: D101.2 (A), MX101.2
unnamed: D102.2 (A), MX102.2
unnamed: C16.1, IC1.20 (VDD33), IC1.23 (ID)
unnamed: IC1.22 (VBUS), R2.1, R7.1
unnamed: C32.2, IC3.1 (INPUT)
unnamed: C33.1, IC3.3 (OUTPUT)
unnamed: J1.2, R11.1
unnamed: LED1.3 (DI), LED2.1 (DO)
unnamed: LED1.1 (DO), LED16.3 (DI)
unnamed: LED2.3 (DI), LED3.1 (DO)
unnamed: LED3.3 (DI), LED4.1 (DO)
unnamed: LED4.3 (DI), LED5.1 (DO)
unnamed: LED5.3 (DI), LED6.1 (DO)
unnamed: LED6.3 (DI), LED7.1 (DO)
unnamed: LED7.3 (DI), LED8.1 (DO)
unnamed: LED8.3 (DI), LED9.1 (DO)
unnamed: LED10.3 (DI), LED11.1 (DO)
unnamed: LED9.3 (DI), LED10.1 (DO)
unnamed: LED11.3 (DI), LED12.1 (DO)
unnamed: LED12.3 (DI), LED13.1 (DO)
unnamed: LED13.3 (DI), LED14.1 (DO)
unnamed: LED14.3 (DI), LED15.1 (DO)
unnamed: LED16.1 (DO), LED17.3 (DI)
unnamed: LED17.1 (DO), LED18.3 (DI)
unnamed: LED18.1 (DO), LED19.3 (DI)
unnamed: LED19.1 (DO), LED20.3 (DI)
unnamed: LED20.1 (DO), LED21.3 (DI)
unnamed: LED21.1 (DO), LED22.3 (DI)
unnamed: LED22.1 (DO), LED23.3 (DI)
unnamed: LED23.1 (DO), LED24.3 (DI)
unnamed: LED24.1 (DO), LED25.3 (DI)
unnamed: LED25.1 (DO), LED26.3 (DI)
unnamed: LED26.1 (DO), LED27.3 (DI)
unnamed: LED27.1 (DO), LED28.3 (DI)
unnamed: LED28.1 (DO), LED29.3 (DI)
unnamed: LED29.1 (DO), LED30.3 (DI)
unnamed: LED30.1 (DO), LED31.3 (DI)
unnamed: LED31.1 (DO), LED47.3 (DI)
unnamed: LED32.3 (DI), LED33.1 (DO)
unnamed: LED32.1 (DO), LED48.3 (DI)
unnamed: LED33.3 (DI), LED34.1 (DO)
unnamed: LED34.3 (DI), LED35.1 (DO)
unnamed: LED35.3 (DI), LED36.1 (DO)
unnamed: LED36.3 (DI), LED37.1 (DO)
unnamed: LED37.3 (DI), LED38.1 (DO)
unnamed: LED38.3 (DI), LED39.1 (DO)
unnamed: LED39.3 (DI), LED40.1 (DO)
unnamed: LED40.3 (DI), LED41.1 (DO)
unnamed: LED41.3 (DI), LED42.1 (DO)
unnamed: LED42.3 (DI), LED43.1 (DO)
unnamed: LED43.3 (DI), LED44.1 (DO)
unnamed: LED44.3 (DI), LED45.1 (DO)
unnamed: LED45.3 (DI), LED46.1 (DO)
unnamed: LED46.3 (DI), LED47.1 (DO)
unnamed: LED48.1 (DO), LED49.3 (DI)
unnamed: LED49.1 (DO), LED50.3 (DI)
unnamed: LED50.1 (DO), LED51.3 (DI)
unnamed: LED51.1 (DO), LED52.3 (DI)
unnamed: LED52.1 (DO), LED53.3 (DI)
unnamed: LED53.1 (DO), LED54.3 (DI)
unnamed: LED54.1 (DO), LED55.3 (DI)
unnamed: LED55.1 (DO), LED56.3 (DI)
unnamed: LED56.1 (DO), LED57.3 (DI)
unnamed: LED57.1 (DO), LED58.3 (DI)
unnamed: LED58.1 (DO), LED59.3 (DI)
unnamed: LED59.1 (DO), LED60.3 (DI)
unnamed: LED60.1 (DO), LED61.3 (DI)
unnamed: LED61.1 (DO), LED62.3 (DI)
unnamed: LED62.1 (DO), LED63.3 (DI)
unnamed: LED63.1 (DO), LED78.3 (DI)
unnamed: LED64.3 (DI), LED65.1 (DO)
unnamed: LED64.1 (DO), LED79.3 (DI)
unnamed: LED65.3 (DI), LED66.1 (DO)
unnamed: LED66.3 (DI), LED67.1 (DO)
unnamed: LED67.3 (DI), LED68.1 (DO)
unnamed: LED68.3 (DI), LED69.1 (DO)
unnamed: LED69.3 (DI), LED70.1 (DO)
unnamed: LED70.3 (DI), LED71.1 (DO)
unnamed: LED71.3 (DI), LED72.1 (DO)
unnamed: LED72.3 (DI), LED73.1 (DO)
unnamed: LED73.3 (DI), LED74.1 (DO)
unnamed: LED74.3 (DI), LED75.1 (DO)
unnamed: LED75.3 (DI), LED76.1 (DO)
unnamed: LED76.3 (DI), LED77.1 (DO)
unnamed: LED77.3 (DI), LED78.1 (DO)
unnamed: LED79.1 (DO), LED80.3 (DI)
unnamed: LED80.1 (DO), LED81.3 (DI)
unnamed: LED81.1 (DO), LED82.3 (DI)
unnamed: LED82.1 (DO), LED83.3 (DI)
unnamed: LED83.1 (DO), LED84.3 (DI)
unnamed: LED84.1 (DO), LED85.3 (DI)
unnamed: LED85.1 (DO), LED86.3 (DI)
unnamed: LED86.1 (DO), LED87.3 (DI)
unnamed: LED87.1 (DO), LED88.3 (DI)
unnamed: LED88.1 (DO), LED89.3 (DI)
unnamed: LED89.1 (DO), LED90.3 (DI)
unnamed: LED90.1 (DO), LED91.3 (DI)
unnamed: LED91.1 (DO), LED92.3 (DI)
unnamed: LED92.1 (DO), LED93.3 (DI)
unnamed: LED94.3 (DI), LED95.1 (DO)
unnamed: LED95.3 (DI), LED96.1 (DO)
unnamed: LED96.3 (DI), LED97.1 (DO)
unnamed: LED97.3 (DI), LED98.1 (DO)
unnamed: LED98.3 (DI), LED99.1 (DO)
unnamed: LED100.3 (DI), LED101.1 (DO)
unnamed: LED99.3 (DI), LED100.1 (DO)
unnamed: LED101.3 (DI), LED102.1 (DO)
unnamed: LED93.1 (DO), LED102.3 (DI)
unnamed: C29.1, MCU1.30 (VCAP_1)
unnamed: R13.1, R14.2, S4.A1 (CHANNEL_A)
unnamed: R4.2, R12.1, S4.B1 (CHANNEL_B)
unnamed: R21.1, R22.2, S4.2 (NO)
unnamed: Polyfuse1.2, Schottky/ReversPolProtec1.2 (A), TVSDiode/ESDSuppr1.1 (K1)
unnamed: C32.1, Schottky/ReversPolProtec1.1 (K)
unnamed: R15.1, USB-C1.A5 (CC1)
unnamed: R1.1, USB-C1.B5 (CC2)
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

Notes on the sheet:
Buck Converters (5->1v8 & 5->3v3)
USB-C CONN & Shield USB_OTG_HS Controller
SWDebug MCU Reset
Mounting Holes
Mechanical Switches
MCU (STM32F446X) JSTPH CONN 25MHz Crystal
LED Array (WS2812B 2020) Push Switch Rotary Encoder 4-Bit Bidirectional Voltage Level Translator

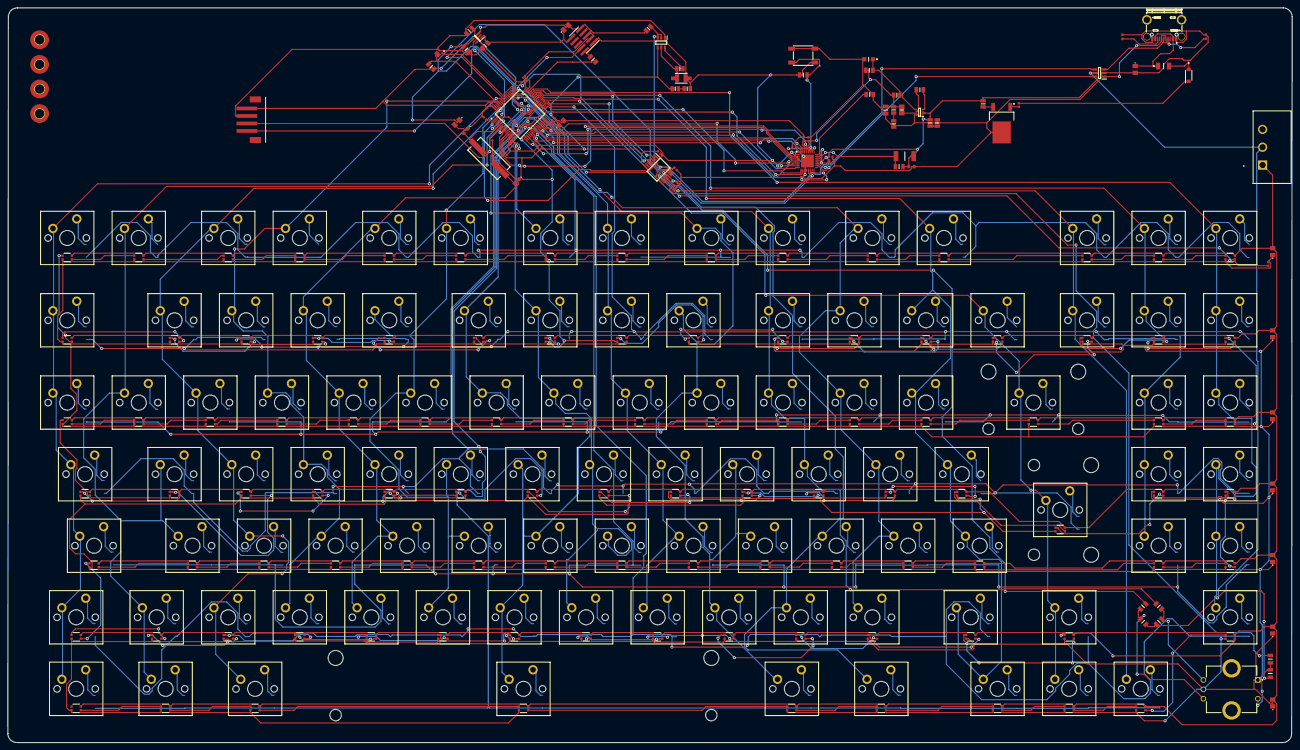
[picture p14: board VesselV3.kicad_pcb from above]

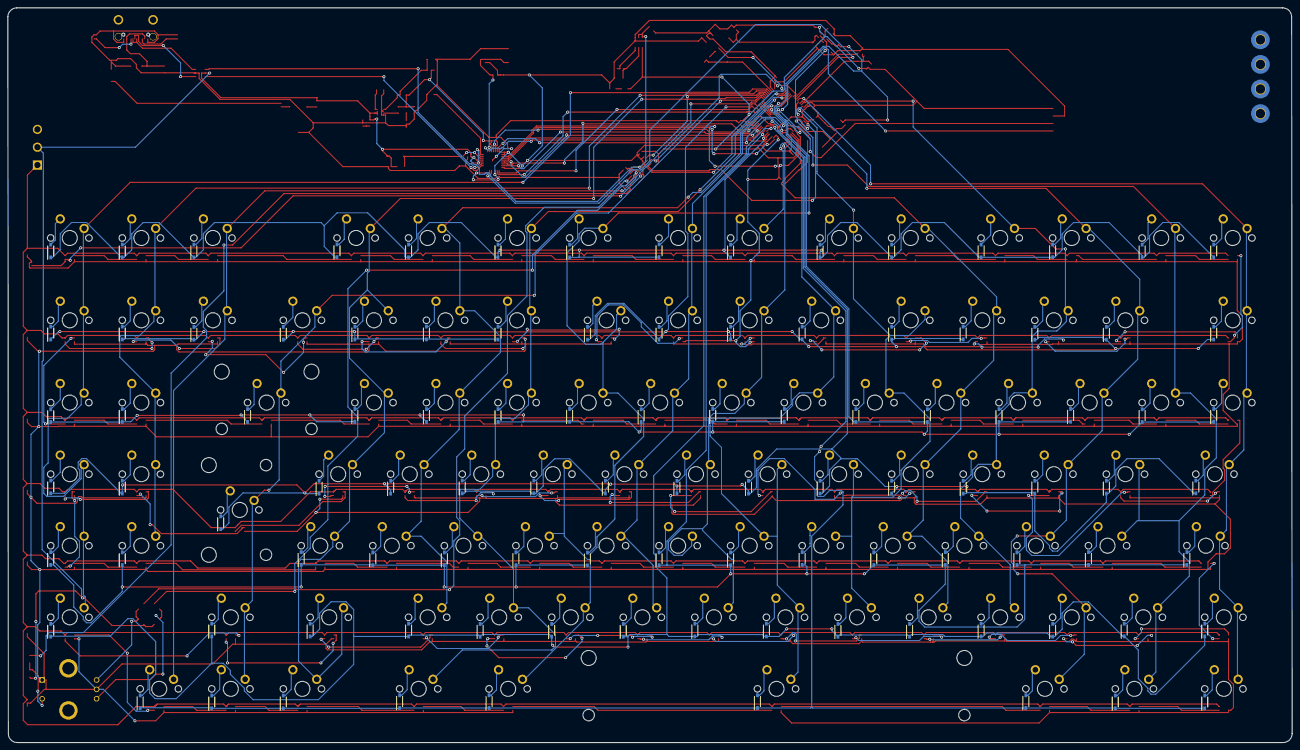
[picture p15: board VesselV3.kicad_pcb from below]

Board: 2 copper layers, 341.8 x 195.5 mm, 398 parts (102 on the bottom side), 292 nets.

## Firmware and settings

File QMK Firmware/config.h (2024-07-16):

// Copyright 2024 Ismael Coulibaly (@Hy-5)
// SPDX-License-Identifier: GPL-2.0-or-later

#pragma once

/*
 * Feature disable options
 *  These options are also useful to firmware size reduction.
 */

/* disable debug print */
//#define NO_DEBUG

/* disable print */
//#define NO_PRINT

/* disable action features */
//#define NO_ACTION_LAYER
//#define NO_ACTION_TAPPING
#define NO_ACTION_ONESHOT
#define MATRIX_IO_DELAY 10
#define LOCKING_SUPPORT_ENABLE
#define IS_COMMAND() (get_mods() == MOD_MASK_SHIFT)
#define USB_MAX_POWER_CONSUMPTION 460
#define USB_POLLING_INTERVAL_MS 2
#define USB_SUSPEND_WAKEUP_DELAY 0
//#define NO_USB_STARTUP_CHECK
#define F_SCL 400000L
#define DEBOUNCE 30
#define TAPPING_TERM 200

// Define direct key switches (not in matrix)
// Rotary encoder push button
#define ENCODERS_PAD_A { A15 }
#define ENCODERS_PAD_B { B10 }
#define KC_ENCODER_PUSH B2
#define ENCODER_RESOLUTION 4
// Boot0 & NRST (for DFU) (Not useful anymore since row0/col12 pressed before plugging in launches bootmagic and goes to DFU bootloader mode)
// #define KC_BOOT0 B4
// #define KC_NRST B3


#define BOOTMAGIC_ROW 0
#define BOOTMAGIC_COLUMN 12


// RGB Config
// #define WS2812_DRIVER bitbang
#define WS2812_DI_PIN A5
#define RGB_MATRIX_LED_COUNT 102
//#define RGBLIGHT RGBLIGHT_WS2812
//#define RGBLIGHT_LED_COUNT 102
#define RGB_MATRIX_DEFAULT_HUE 0
#define RGB_MATRIX_DEFAULT_SAT 255
#define RGB_MATRIX_DEFAULT_SPD 127
// #define RGBLIGHT_HUE_STEP 8
// #define RGBLIGHT_SAT_STEP 17
// #define RGBLIGHT_VAL_STEP 17
// #define RGBLIGHT_DEFAULT_MODE 6
#define RGB_MATRIX_MAXIMUM_BRIGHTNESS 180
#define RGB_MATRIX_DEFAULT_VAL 160
#define RGB_MATRIX_DEFAULT_ON true
// #define RGBLIGHT_LIMIT_VAL 120
// #define RGBLIGHT_DEFAULT_VAL 100
// #define RGBLIGHT_DEFAULT_ON true

// RGB Matrix defines:
// #define ENABLE_RGB_MATRIX_ALPHAS_MODS
// #define ENABLE_RGB_MATRIX_GRADIENT_UP_DOWN
#define ENABLE_RGB_MATRIX_GRADIENT_LEFT_RIGHT
#define ENABLE_RGB_MATRIX_BREATHING
#define ENABLE_RGB_MATRIX_BAND_SAT
#define ENABLE_RGB_MATRIX_BAND_VAL
#define ENABLE_RGB_MATRIX_BAND_PINWHEEL_SAT
#define ENABLE_RGB_MATRIX_BAND_PINWHEEL_VAL
#define ENABLE_RGB_MATRIX_BAND_SPIRAL_SAT
#define ENABLE_RGB_MATRIX_BAND_SPIRAL_VAL
#define ENABLE_RGB_MATRIX_CYCLE_ALL
#define ENABLE_RGB_MATRIX_CYCLE_LEFT_RIGHT
#define ENABLE_RGB_MATRIX_CYCLE_UP_DOWN
#define ENABLE_RGB_MATRIX_RAINBOW_MOVING_CHEVRON
#define ENABLE_RGB_MATRIX_CYCLE_OUT_IN
#define ENABLE_RGB_MATRIX_CYCLE_OUT_IN_DUAL
#define ENABLE_RGB_MATRIX_CYCLE_PINWHEEL
#define ENABLE_RGB_MATRIX_CYCLE_SPIRAL
#define ENABLE_RGB_MATRIX_DUAL_BEACON
#define ENABLE_RGB_MATRIX_RAINBOW_BEACON
#define ENABLE_RGB_MATRIX_RAINBOW_PINWHEELS
#define ENABLE_RGB_MATRIX_FLOWER_BLOOMING
// #define ENABLE_RGB_MATRIX_RAINDROPS
// #define ENABLE_RGB_MATRIX_JELLYBEAN_RAINDROPS
#define ENABLE_RGB_MATRIX_HUE_BREATHING
#define ENABLE_RGB_MATRIX_HUE_PENDULUM
#define ENABLE_RGB_MATRIX_HUE_WAVE
// #define ENABLE_RGB_MATRIX_PIXEL_FRACTAL
#define ENABLE_RGB_MATRIX_PIXEL_FLOW
// #define ENABLE_RGB_MATRIX_PIXEL_RAIN
#define ENABLE_RGB_MATRIX_STARLIGHT
#define ENABLE_RGB_MATRIX_STARLIGHT_DUAL_HUE
#define ENABLE_RGB_MATRIX_STARLIGHT_DUAL_SAT
#define ENABLE_RGB_MATRIX_RIVERFLOW
#define ENABLE_RGB_MATRIX_SOLID_REACTIVE_SIMPLE
#define ENABLE_RGB_MATRIX_SOLID_REACTIVE
#define ENABLE_RGB_MATRIX_SOLID_REACTIVE_WIDE
#define ENABLE_RGB_MATRIX_SOLID_REACTIVE_MULTIWIDE
#define ENABLE_RGB_MATRIX_SOLID_REACTIVE_CROSS
#define ENABLE_RGB_MATRIX_SOLID_REACTIVE_MULTICROSS
#define ENABLE_RGB_MATRIX_SOLID_REACTIVE_NEXUS
#define ENABLE_RGB_MATRIX_SOLID_REACTIVE_MULTINEXUS
#define ENABLE_RGB_MATRIX_SPLASH
#define ENABLE_RGB_MATRIX_MULTISPLASH
#define ENABLE_RGB_MATRIX_SOLID_SPLASH
#define ENABLE_RGB_MATRIX_SOLID_MULTISPLASH

// Framebuffer Defines 	Description
// #define ENABLE_RGB_MATRIX_TYPING_HEATMAP
// #define ENABLE_RGB_MATRIX_DIGITAL_RAIN
// Automatically change reactive color
#define RGB_MATRIX_SOLID_REACTIVE_GRADIENT_MODE

// RGB Modes
#define RGB_MATRIX_DEFAULT_MODE RGB_MATRIX_SOLID_REACTIVE_MULTIWIDE
// #define RGBLIGHT_EFFECT_RAINBOW_MOOD
// #define RGBLIGHT_EFFECT_RAINBOW_SWIRL
// #define RGBLIGHT_MODE_STATIC_LIGHT
// #define RGBLIGHT_MODE_BREATHING
// #define RGBLIGHT_MODE_SNAKE
// #define RGBLIGHT_MODE_KNIGHT
// #define RGBLIGHT_MODE_CHRISTMAS
// #define RGBLIGHT_MODE_STATIC_GRADIENT
// #define RGBLIGHT_MODE_ALTERNATING
// #define RGBLIGHT_MODE_TWINKLE
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

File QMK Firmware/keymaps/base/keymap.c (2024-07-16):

// Copyright 2023 QMK
// SPDX-License-Identifier: GPL-2.0-or-later

#include QMK_KEYBOARD_H
#include "keymap_french.h"
#include "print.h"
#include "timer.h"
#include "quantum.h"


/***** rgblight_mode(mode)/rgblight_mode_noeeprom(mode) ****
    
    SHOULD WORK with new name modes but for some reason won't compile unless I give it the number instead. Last time tested QMK 0.23.5
    
    |-----------------|-----------------------------------|
    | old mode number | new mode name                     |
    |-----------------|-----------------------------------|
    |        1        | RGBLIGHT_MODE_STATIC_LIGHT        |
    |        2        | RGBLIGHT_MODE_BREATHING           |
    |        3        | RGBLIGHT_MODE_BREATHING + 1       |
    |        4        | RGBLIGHT_MODE_BREATHING + 2       |
    |        5        | RGBLIGHT_MODE_BREATHING + 3       |
    |        6        | RGBLIGHT_MODE_RAINBOW_MOOD        |
    |        7        | RGBLIGHT_MODE_RAINBOW_MOOD + 1    |
    |        8        | RGBLIGHT_MODE_RAINBOW_MOOD + 2    |
    |        9        | RGBLIGHT_MODE_RAINBOW_SWIRL       |
    |       10        | RGBLIGHT_MODE_RAINBOW_SWIRL + 1   |
    |       11        | RGBLIGHT_MODE_RAINBOW_SWIRL + 2   |
    |       12        | RGBLIGHT_MODE_RAINBOW_SWIRL + 3   |
    |       13        | RGBLIGHT_MODE_RAINBOW_SWIRL + 4   |
    |       14        | RGBLIGHT_MODE_RAINBOW_SWIRL + 5   |
    |       15        | RGBLIGHT_MODE_SNAKE               |
    |       16        | RGBLIGHT_MODE_SNAKE + 1           |
    |       17        | RGBLIGHT_MODE_SNAKE + 2           |
    |       18        | RGBLIGHT_MODE_SNAKE + 3           |
    |       19        | RGBLIGHT_MODE_SNAKE + 4           |
    |       20        | RGBLIGHT_MODE_SNAKE + 5           |
    |       21        | RGBLIGHT_MODE_KNIGHT              |
    |       22        | RGBLIGHT_MODE_KNIGHT + 1          |
    |       23        | RGBLIGHT_MODE_KNIGHT + 2          |
    |       24        | RGBLIGHT_MODE_CHRISTMAS           |
    |       25        | RGBLIGHT_MODE_STATIC_GRADIENT     |
    |       26        | RGBLIGHT_MODE_STATIC_GRADIENT + 1 |
    |       27        | RGBLIGHT_MODE_STATIC_GRADIENT + 2 |
    |       28        | RGBLIGHT_MODE_STATIC_GRADIENT + 3 |
    |       29        | RGBLIGHT_MODE_STATIC_GRADIENT + 4 |
    |       30        | RGBLIGHT_MODE_STATIC_GRADIENT + 5 |
    |       31        | RGBLIGHT_MODE_STATIC_GRADIENT + 6 |
    |       32        | RGBLIGHT_MODE_STATIC_GRADIENT + 7 |
    |       33        | RGBLIGHT_MODE_STATIC_GRADIENT + 8 |
    |       34        | RGBLIGHT_MODE_STATIC_GRADIENT + 9 |
    |       35        | RGBLIGHT_MODE_RGB_TEST            |
    |       36        | RGBLIGHT_MODE_ALTERNATING         |
    |       37        | RGBLIGHT_MODE_TWINKLE             |
    |       38        | RGBLIGHT_MODE_TWINKLE + 1         |
    |       39        | RGBLIGHT_MODE_TWINKLE + 2         |
    |       40        | RGBLIGHT_MODE_TWINKLE + 3         |
    |       41        | RGBLIGHT_MODE_TWINKLE + 4         |
    |       42        | RGBLIGHT_MODE_TWINKLE + 5         |
    |-----------------|-----------------------------------|
*****/

// custom keycode example
enum custom_keycodes {
    KC_PrevDesk = SAFE_RANGE, // Custom keycode for Ctrl+Windows+Left
    KC_NextDesk,              // Custom keycode for Ctrl+Windows+Right
};
#if defined (TAP_DANCE_ENABLE)
    // Tap Dance declarations
    enum {
        TD_M_RC,
        TD_A_RW,
    };
    
    // Tap Dance definitions
    tap_dance_action_t tap_dance_actions[] = {
        // Tap once for Menu, twice for Right Control
        [TD_M_RC] = ACTION_TAP_DANCE_DOUBLE(KC_APP, KC_RCTL),
        // Tap once for Right Alt, twice for Right Windows
        [TD_A_RW] = ACTION_TAP_DANCE_DOUBLE(KC_RALT, KC_RGUI),
    };
    
    
#endif

const uint16_t PROGMEM keymaps[][MATRIX_ROWS][MATRIX_COLS] = {
    
    /*
        *┌───┬───┐ ┌───┬───┐ ┌───┬───┐ ┌───┬───┐ ┌───┬───┐ ┌───┬───┐ ┌───┬───┬───┐
        *│M1 │M2 │ │M3 │M4 │ │M5 │M6 │ │M7 │M8 │ │M9 │M10│ │M11│M12│ │Pre│Pla│Nex│
        *└───┴───┘ └───┴───┘ └───┴───┘ └───┴───┘ └───┴───┘ └───┴───┘ └───┴───┴───┘
        *┌───┐ ┌───┬───┬───┬───┐ ┌───┬───┬───┬───┐ ┌───┬───┬───┬───┐ ┌───┬───┬───┐
        *│Esc│ │F1 │F2 │F3 │F4 │ │F5 │F6 │F7 │F8 │ │F9 │F10│F11│F12│ │PSc│OC │Lay│
        *└───┘ └───┴───┴───┴───┘ └───┴───┴───┴───┘ └───┴───┴───┴───┘ └───┴───┴───┘
        *┌───┬───┬───┬───┬───┬───┬───┬───┬───┬───┬───┬───┬───┬───────┐   ┌───┬───┐
        *│ ² │ 1 │ 2 │ 3 │ 4 │ 5 │ 6 │ 7 │ 8 │ 9 │ 0 │ ° │ + │ Backsp│   │Hom│End│
        *├───┴─┬─┴─┬─┴─┬─┴─┬─┴─┬─┴─┬─┴─┬─┴─┬─┴─┬─┴─┬─┴─┬─┴─┬─┴─┬─────┤   ├───┼───┤
        *│ Tab │ A │ Z │ E │ R │ T │ Y │ U │ I │ O │ P │ ¨ │ £ │     │   │Ins│PUp│
        *├─────┴┬──┴┬──┴┬──┴┬──┴┬──┴┬──┴┬──┴┬──┴┬──┴┬──┴┬──┴┬──┴┐ Ent│   ├───┼───┤
        *│ Caps │ Q │ S │ D │ F │ G │ H │ J │ K │ L │ M │ % │ µ │    │   │Del│PDn│             
        *├────┬─┴─┬─┴─┬─┴─┬─┴─┬─┴─┬─┴─┬─┴─┬─┴─┬─┴─┬─┴─┬─┴─┬─┴───┴┬───┤   └───┼───┤   
        *│Shft│ > │ W │ X │ C │ V │ B │ N │ ? │ . │ / │ § │Shift │ ↑ │       │T22│
        *├────┼───┴┬──┴─┬─┴───┴───┴───┴───┴───┴──┬┴───┼───┴┬─┬───┼───┼───┐ ┌─┴───┤
        *│Ctrl│GUI │Alt │          Space         │Alt │Menu│ │ ← │ ↓ │ → │ │(Enc)│
        *└────┴────┴────┴────────────────────────┴────┴────┘ └───┴───┴───┘ └─────┘
        *
    */
    
    
    [0] = LAYOUT_all(
        KC_F13,           KC_F14,   KC_F15,   KC_F16,   KC_F17,   KC_F18,   KC_F19,   KC_F20,   KC_F21,   KC_F22,   KC_F23,  KC_F24,     KC_MPRV, KC_MPLY, KC_MNXT,
        KC_ESC,           KC_F1,   KC_F2,   KC_F3,   KC_F4,   KC_F5,   KC_F6,   KC_F7,   KC_F8,   KC_F9,   KC_F10,  KC_F11,  KC_F12,     KC_PSCR, PB_1, PB_2,
        KC_GRV,  KC_1,    KC_2,    KC_3,    KC_4,    KC_5,    KC_6,    KC_7,    KC_8,    KC_9,    KC_0,    KC_MINS, KC_EQL,  KC_BSPC,    KC_HOME, KC_END,
        KC_TAB,  KC_Q,    KC_W,    KC_E,    KC_R,    KC_T,    KC_Y,    KC_U,    KC_I,    KC_O,    KC_P,    KC_LBRC, KC_RBRC, KC_ENT,     KC_INS,  KC_PGUP,
        KC_CAPS, KC_A,    KC_S,    KC_D,    KC_F,    KC_G,    KC_H,    KC_J,    KC_K,    KC_L,    KC_SCLN, KC_QUOT, KC_NUHS,             KC_DEL,  KC_PGDN,
        KC_LSFT, KC_NUBS, KC_Z,    KC_X,    KC_C,    KC_V,    KC_B,    KC_N,    KC_M,    KC_COMM, KC_DOT,  KC_SLSH, KC_RSFT,  KC_UP,              PB_3,
        KC_LCTL, KC_LGUI, KC_LALT,                            KC_SPC,                             TD(TD_A_RW), TD(TD_M_RC), KC_LEFT, KC_DOWN, KC_RGHT
    )
};

#if defined(ENCODER_MAP_ENABLE)
    const uint16_t PROGMEM encoder_map[][NUM_ENCODERS][NUM_DIRECTIONS] = {
        [0] = { ENCODER_CCW_CW(KC_PrevDesk, KC_NextDesk)  },
    };
#endif
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

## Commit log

2023-11-10 Buck Converter and inductor added
    [VesselV3.kicad_pcb, VesselV3.kicad_sch]
2023-11-11 On/Off DPDT - Electrolytic Cap - Initial LED
    [VesselV3.kicad_sch]
2023-11-12 OLED indicator- LED arrays - minor fixes
    [VesselV3.kicad_sch]
2023-11-17 Fixed LED connection and positioning
    [VesselV3.kicad_sch]
2023-11-21 Fixing oscillator parallel connection
    [VesselV3.kicad_sch]
2023-11-21 OTG_HS_ULPI Initial Config - 1v8 Buck Added
    [VesselV3.kicad_sch]
2023-11-22 Fixed External Oscillator Circuit
    [VesselV3.kicad_sch]
2023-11-22 Final Schematics - Additional Corrections WIP
    [VesselV3.kicad_sch]
2023-11-23 Page Cleanup - Decoup CAP & Pull up Resistors
    [VesselV3.kicad_sch]
2023-11-23 ESD & Reverse Pol protections / + 5V regulator
    [VesselV3.kicad_sch]
2023-11-23 Removed stray 5V, Added additional Caps
    [VesselV3.kicad_sch]
2023-11-24 USB OTG D- & D+ fixes/Additional corrections
    [VesselV3.kicad_sch]
2023-11-25 Further fixes - Ibis models added
    [VesselV3.kicad_sch]
2023-11-26 Rotary Enc 3V3 logic needs shifting to 5V (WIP)
    [VesselV3.kicad_sch]
2023-11-26 Voltage Level Translator swapped - Rotary encoder fixed
    [VesselV3.kicad_sch]
2023-11-26 DFU compat, PNP Transistor, Pull-up resistors
    [VesselV3.kicad_sch]
2023-11-26 Fixed LED GND/HSE Oscillator symbols
    [VesselV3.kicad_sch]
2023-11-28 Initial PCB Board Setup
    [VesselV3.kicad_pcb, VesselV3.kicad_sch]
2023-11-28 PCB layout - Initial Commit
    [VesselV3.kicad_pcb, VesselV3.kicad_sch]
2023-11-28 Rough PCB Layout and GPIO Pins Swaps
    [VesselV3.kicad_pcb, VesselV3.kicad_sch]
2023-11-29 Swapped encoder for smaller one
    [VesselV3.kicad_pcb, VesselV3.kicad_sch]
2023-12-05 Fully Routed PCB
    [VesselV3.kicad_pcb, VesselV3.kicad_sch]
2023-12-06 Fixed DRC Errors
    [VesselV3.kicad_pcb, VesselV3.kicad_sch]
2023-12-06 Encoder Push - Pull-up and DRC
    [VesselV3.kicad_pcb, VesselV3.kicad_sch]
2023-12-06 Improved routing
    [VesselV3.kicad_pcb]
2023-12-08 Traces separation - DRC Fixes
2023-12-11 USB ESD -> Internal ESD in USB3320 IC
    [VesselV3.kicad_sch]
2023-12-11 Additional Fixes
    [VesselV3.kicad_sch]
2023-12-13 Before USB_HS Impedance Matching
    [VesselV3.kicad_sch]
2023-12-13 Typo Fixes
    [VesselV3.kicad_sch]
2023-12-15 Led15_DI_Cap Routing fix - 3D Case Initial Commit
    [SwitchLayerFile.FCStd, UpdatedSwitchLayer.dxf, VesselV3.kicad_sch]
2023-12-15 Fixed Switch Layer
    [SwitchLayerFile.FCStd]
2023-12-15 Initial Case bottom layer
2023-12-16 Imported Converted OLED PCB
2023-12-16 Prelim. PMMA Case - 3 Layers (Bottom/Switch/Top)
2023-12-16 USB VBUS trace width fixed
2023-12-17 PMMA OLED Hole Adjustment
    [BottomLayerBody.step, SideCoverLayer.step, SwitchLayerBody.step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]
2023-12-17 WIP (Layers Normalization/PMMA integrity adjustments)
    [BottomLayerBody.step, SideCoverLayer.step, SwitchLayerBody.step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]
2023-12-18 Repositioned Encoder - PMMA Layer Adjustments
2023-12-18 Size Adjustments
    [BottomLayerBody.step, SideCoverLayer.step, SwitchLayerBody.step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]
2023-12-20 Capacitors repositioning-PMMA Layers Alignment-Keycap Swap
    [BottomLayerBody.step, SideCoverLayer.step, SwitchLayerBody.step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]
2023-12-21 MountingHoles/Inserts/Screws Added
    [BottomLayerBody.step, SideCoverLayer.step, SwitchLayerBody.step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]
2023-12-21 Small fixes to PMMA mounting holes and inserts
    [BottomLayerBody.step, SideCoverLayer.step, SwitchLayerBody.step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]
2023-12-21 PMMA Insert Holes adjustments
    [BottomLayerBody.step, SideCoverLayer.step, SwitchLayerBody.step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]
2023-12-21 Mounting Holes and PMMA Adjustments
    [BottomLayerBody.step, SideCoverLayer.step, SwitchLayerBody.step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]
2023-12-23 Fixed mounting holes
    [VesselV3.kicad_sch]
2023-12-24 Fixed PMMA Switch Layer Mounting hole
    [BottomLayerBody.step, SideCoverLayer.step, SwitchLayerBody.step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]
2023-12-26 Fixed Caps on Voltage Regulators
    [VesselV3.kicad_sch]
2023-12-26 Swapped BuckConvs for Dual output voltage regs
    [VesselV3.kicad_sch]
2023-12-26 Freecad PCB updated
2023-12-27 (WIP) - Simpler PCB design and routing
    [VesselV3(Keepon).kicad_pcb, VesselV3(USB_HS).kicad_sch, VesselV3.kicad_sch]
2023-12-27 Added 2nd (USB_FS) PCB & PMMA Layers (Schematic, Routing & PMMA)
    [VesselV3(Keepon).kicad_pcb, VesselV3.kicad_sch]
2023-12-28 Fixed Bottom Left Mounting hole and Adjusted PMMA
    [BottomLayerBody.step, SideCoverLayer.step, SwitchLayerBody.step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]
2023-12-28 3V3 traces widened (0.2->0.3mm)
2023-12-30 Trace clearance fixed and some silkscreen added
2023-12-30 Minor Fixes
    [BottomLayerBody.step, SideCoverLayer.step, SwitchLayerBody.step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]
2023-12-31 Silkscreen modified
2024-01-01 Swapped QFN 3v3 Linear Reg for SOT25 3v3 LDO Reg
    [VesselV3.kicad_sch]
2024-01-05 PCB : +4 Solder jumpers, -RPd (NRST), Routing fix
    [VesselV3.kicad_sch]
2024-01-09 FMPI²c to I²c Swap and routing fix
    [VesselV3.kicad_sch]
2024-01-12 Swapped 0402 TVS for SOD123 - Other Routing Fixes
    [BottomLayerBody.step, SideCoverLayer.step, SwitchLayerBody.step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]
2024-01-12 Swapped Schottky Rectifier for lower Vf
    [VesselV3.kicad_sch, temp-freerouting.dsn]
2024-01-21 PMMA layers adjustments
    [BottomLayerBody.step, SideCoverLayer.step, SwitchLayerBody.step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]
2024-01-21 PMMA Layers Adjusted further - Final Fillets
    [BottomLayerBody.step, SideCoverLayer.step, SwitchLayerBody.step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]
2024-01-21 Swapped PNP Transistor QFN for SOT123 Package- Updated PMMA
    [VesselV3.kicad_sch]
2024-02-01 New LDO - 1.5 Amps compatibility test start
    [BottomLayerBody.step, OldVesselKB.csv, SideCoverLayer.step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]
2024-02-01 USB PD Preliminary implementation test (Deprecated)
    [VesselKB.csv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]
2024-02-02 Back to 600mA LDO regulator
    [VesselKB.csv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]
2024-02-05 Final test Points added - Tracks and Vias cleanup
    [VesselV3-B_Cu.gbr, VesselV3-B_Mask.gbr, VesselV3-B_Paste.gbr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]
2024-02-05 Pre 0402 Swap
    [VesselV3-F_Silkscreen.dxf]
2024-02-06 Swapped 0402s for 0805s
    [VesselKB.csv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]
2024-02-17 Fixed front silkscreen
    [1 - BottomLayer.step, 2 - TopLayer.step, 3 - SwitchLayer.step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]
2024-03-14 Fully Working firmware (LED in Bitbang mode) - PWM Work In Progress
2024-03-26 Cleanup and readme fix
    [keymap.c]
2024-03-27 OLED Toggle and Auto-Timeout fixed
    [keymap.c]
2024-03-27 OLED Fixes - Readme Update
    [keymap.c]
2024-04-28 Misc Updates
    [VesselV3.kicad_sch]
2024-05-09 LED_MATRIX initial commit
2024-05-09 LED_MATRIX fixed
2024-05-09 LED_MATRIX additional fixes
2024-12-22 Added missing CAD screenshots
2024-12-22 Update README.md
    Added Case pre-production screenshots
